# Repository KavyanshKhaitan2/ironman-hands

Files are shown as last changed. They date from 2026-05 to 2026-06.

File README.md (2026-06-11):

# Ironman-Hands!
[View in OnShape](https://cad.onshape.com/documents/6b24d13ccce8b20dadd52a3a/w/196c8f17dbb1cb6e287c322c/e/852bd395ec118001130bafdd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)

A glove which you can wear and control your computer by moving your hand and using gestures!! (It has a lot of sensors to do this!)

I will be stitching all the parts together on a glove, and then adding some more cloth on top so no exposed wires or PCBs are visible!

## Contents
Quickly jump to different parts of the README using this section!
1. [Why?](#why)
1. [Fallout Zine](#fallout-zine)
2. [PCB](#pcb)
3. [Schematics](#schematics)
4. [Case](#case)
5. [Bill of Materials](#bom)
6. [Assembly](#assembly)
## Why?
I watched the Iron Man Movie, and it was always fascinating to me how he controlled the screen using just his hands, so I decided to build to make that true and real!

## Fallout Zine
[Jump to Contents](#contents)

<image height="400" src="https://github.com/KavyanshKhaitan2/ironman-hands/blob/main/zine/Zine_PNG.png?raw=true">

- [ [Download JPEG file](https://github.com/KavyanshKhaitan2/ironman-hands/blob/main/zine/Zine_JPEG.jpg) ]
- [ [Download PNG file](https://github.com/KavyanshKhaitan2/ironman-hands/blob/main/zine/Zine_PNG.png) ]
- [ [Download High-Res PNG file](https://github.com/KavyanshKhaitan2/ironman-hands/blob/main/zine/Zine_PNG_HighRes.png) ]
- [ [Download Digital RGB PDF file](https://github.com/KavyanshKhaitan2/ironman-hands/blob/main/zine/Zine_Digital_RGB.pdf) ]
- [ [Download Print CMYK PDF file](https://github.com/KavyanshKhaitan2/ironman-hands/blob/main/zine/Zine_Print_CMYK.pdf) ]

[Jump to Contents](#contents)

## PCB
[Jump to Contents](#contents)

- [Mainboard](#mainboard)
- [Finger module](#finger-module)
- [BackLEDs](#backleds)
- [Power module](#power-module)

### Mainboard


- [ [Open in KiCanvas](https://kicanvas.org/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) ]

[Jump to Contents](#contents)

### Finger module


- [ [Open in KiCanvas](https://kicanvas.org/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) ]

[Jump to Contents](#contents)

### BackLEDs


- [ [Open in KiCanvas](https://kicanvas.org/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) ]

[Jump to Contents](#contents)

### Power module


- [ [Open in KiCanvas](https://kicanvas.org/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) ]

[Jump to Contents](#contents)

## Schematics
[Jump to Contents](#contents)

- [Mainboard](#mainboard-1)
- [Finger module P1](#finger-module-p1)
- [Finger module P2](#finger-module-p2)
- [Power module](#power-module-1)

### Mainboard


[ [View in KiCanvas](https://kicanvas.org/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) ]

[Jump to Contents](#contents)

### Finger module P1


[ [View in KiCanvas](https://kicanvas.org/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) ]

[Jump to Contents](#contents)

### Finger module P2


[ [View in KiCanvas](https://kicanvas.org/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) ]

[Jump to Contents](#contents)

### Power module


[ [View in KiCanvas](https://kicanvas.org/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) ]

[Jump to Contents](#contents)

## Case
### Final assembly:


[ [View in OnShape](https://cad.onshape.com/documents/6b24d13ccce8b20dadd52a3a/w/196c8f17dbb1cb6e287c322c/e/852bd395ec118001130bafdd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) ]

[Jump to Contents](#contents)

## BOM
(Bill of Materials)

[ [View in Google Sheets](https://docs.google.com/spreadsheets/d/10JJsmnbrsMaL60rsXx-CBmIgtjZ1htyX9JACOBp3yb4/edit?usp=sharing) ]
[ [Open CSV in GitHub](https://github.com/KavyanshKhaitan2/ironman-hands/blob/main/production/BOM.csv) ]

- [Cumulative](#cumulative)
- [Mainboard](#mainboard)
- [Per-finger module](#per-finger-module)
- [Power](#power)
- [Misc](#misc)

[Jump to Contents](#contents)

### Cumulative


[Jump to Contents](#contents)

### Mainboard
<table cellspacing="0" cellpadding="0">
    <tr>
        <th>
            <div>2</div>
        </th>
        <td>PCB</td>
        <td>0.4000</td>
        <td>
            <span>USD</span>
        </td>
        <td>-</td>
        <td>5</td>
        <td>1</td>
        <td>2.00</td>
        <td>USD</td>
        <td>₹191.36</td>
        <td>$2.00</td>
    </tr>
    <tr>
        <th>
            <div>3</div>
        </th>
        <td>Header pins (90deg)</td>
        <td>0.2000</td>
        <td>
            <span>INR</span>
        </td>
        <td>
            <a href="https://quartzcomponents.com/collections/all/products/male-90-degree-pin-header-connector"
                >QuartzComponents</a
            >
        </td>
        <td>40</td>
        <td>34</td>
        <td>8.00</td>
        <td>INR</td>
        <td>₹199.36</td>
        <td>$2.08</td>
    </tr>
    <tr>
        <th>
            <div>4</div>
        </th>
        <td>TYPE-C-31-M-12</td>
        <td>0.1719</td>
        <td>
            <span>USD</span>
        </td>
        <td>
            <a href="https://www.lcsc.com/product-detail/C165948.html">LCSC</a>
        </td>
        <td>5</td>
        <td>1</td>
        <td>0.86</td>
        <td>USD</td>
        <td>₹281.60</td>
        <td>$2.94</td>
    </tr>
    <tr>
        <th>
            <div>5</div>
        </th>
        <td>LM1117MP-3.3/TR</td>
        <td>0.0931</td>
        <td>
            <span>USD</span>
        </td>
        <td>
            <a href="https://www.lcsc.com/product-detail/C498153.html">LCSC</a>
        </td>
        <td>5</td>
        <td>1</td>
        <td>0.47</td>
        <td>USD</td>
        <td>₹326.14</td>
        <td>$3.41</td>
    </tr>
    <tr>
        <th>
            <div>6</div>
        </th>
        <td>SS56 Diode</td>
        <td>0.0471</td>
        <td>
            <span>USD</span>
        </td>
        <td>
            <a href="https://www.lcsc.com/product-detail/C65009.html">LCSC</a>
        </td>
        <td>10</td>
        <td>1</td>
        <td>0.47</td>
        <td>USD</td>
        <td>₹371.21</td>
        <td>$3.88</td>
    </tr>
    <tr>
        <th>
            <div>7</div>
        </th>
        <td>ESP32-S3-WROOM-1</td>
        <td>371.0000</td>
        <td>
            <span>INR</span>
        </td>
        <td>
            <a href="https://www.etstore.in/products/a2724">ETStore</a>
        </td>
        <td>1</td>
        <td>1</td>
        <td>371.00</td>
        <td>INR</td>
        <td>₹742.21</td>
        <td>$7.76</td>
    </tr>
    <tr>
        <th>
            <div>8</div>
        </th>
        <td>LSM6DS3TR-C</td>
        <td>1.5474</td>
        <td>
            <span>USD</span>
        </td>
        <td>
            <a href="https://www.lcsc.com/product-detail/C967633.html">LCSC</a>
        </td>
        <td>1</td>
        <td>1</td>
        <td>1.55</td>
        <td>USD</td>
        <td>₹890.27</td>
        <td>$9.30</td>
    </tr>
    <tr>
        <th>
            <div>9</div>
        </th>
        <td>TCA9548APWR</td>
        <td>0.6418</td>
        <td>
            <span>USD</span>
        </td>
        <td>
            <a href="https://www.lcsc.com/product-detail/C130026.html">LCSC</a>
        </td>
        <td>1</td>
        <td>1</td>
        <td>0.64</td>
        <td>USD</td>
        <td>₹951.68</td>
        <td>$9.95</td>
    </tr>
    <tr>
        <th>
            <div>10</div>
        </th>
        <td>SK6812MINI-E</td>
        <td>0.0870</td>
        <td>
            <span>USD</span>
        </td>
        <td>
            <a href="https://www.lcsc.com/product-detail/C5149201.html">LCSC</a>
        </td>
        <td>5</td>
        <td>6</td>
        <td>0.87</td>
        <td>USD</td>
        <td>₹1,034.92</td>
        <td>$10.82</td>
    </tr>
    <tr>
        <th>
            <div>11</div>
        </th>
        <td>10k 1206 resistor</td>
        <td>0.4500</td>
        <td>
            <span>INR</span>
        </td>
        <td>
            <a
                href="https://quartzcomponents.com/collections/all/products/yageo-510k-ohm-1206-package-1-4w-smd-resistor-1-tolerance-pack-of-20-pieces"
                >QuartzComponents</a
            >
        </td>
        <td>20</td>
        <td>2</td>
        <td>9.00</td>
        <td>INR</td>
        <td>₹1,043.92</td>
        <td>$10.91</td>
    </tr>
    <tr>
        <th>
            <div>12</div>
        </th>
        <td>100nF 0805 capacitor</td>
        <td>1.5000</td>
        <td>
            <span>INR</span>
        </td>
        <td>
            <a
                href="https://quartzcomponents.com/collections/all/products/100nf-0-1uf-104-50v-1206-smd-capacitor-pack-of-10-pieces"
                >QuartzComponents</a
            >
        </td>
        <td>10</td>
        <td>2</td>
        <td>15.00</td>
        <td>INR</td>
        <td>₹1,058.92</td>
        <td>$11.07</td>
    </tr>
</table>

[Jump to Contents](#contents)

### Per-finger module
<table cellspacing="0" cellpadding="0">
    <tbody>
        <tr>
            <td>Item Name</td>
            <td>
                <div>Unit Price</div>
            </td>
            <td>
                <div>Cur.</div>
            </td>
            <td>Link</td>
            <td>
                <div>Min Qty.</div>
            </td>
            <td>
                <div>Qty.</div>
            </td>
            <td>
                <div>Amount</div>
            </td>
            <td>Co1</td>
            <td>
                <div>1.. Run. Total</div>
            </td>
            <td>
                <div>2.. Run. Total</div>
            </td>
        </tr>
        <tr>
            <td>PCB</td>
            <td>0.4000</td>
            <td>
                <span>USD</span>
            </td>
            <td>-</td>
            <td>5</td>
            <td>4</td>
            <td>2.00</td>
            <td>USD</td>
            <td>₹191.36</td>
            <td>$2.00</td>
        </tr>
        <tr>
            <td>Header pins (90deg)</td>
            <td>0.2000</td>
            <td>
                <span>INR</span>
            </td>
            <td>
                <a href="https://quartzcomponents.com/collections/all/products/male-90-degree-pin-header-connector"
                    >QuartzComponents</a
                >
            </td>
            <td>40</td>
            <td>18</td>
            <td>8.00</td>
            <td>INR</td>
            <td>₹199.36</td>
            <td>$2.08</td>
        </tr>
        <tr>
            <td>LSM6DS3TR-C</td>
            <td>1.5474</td>
            <td>
                <span>USD</span>
            </td>
            <td>
                <a href="https://www.lcsc.com/product-detail/C967633.html">LCSC</a>
            </td>
            <td>1</td>
            <td>2</td>
            <td>3.09</td>
            <td>USD</td>
            <td>₹495.48</td>
            <td>$5.18</td>
        </tr>
        <tr>
            <td>10k 1206 resistor</td>
            <td>0.4500</td>
            <td>
                <span>INR</span>
            </td>
            <td>
                <a
                    href="https://quartzcomponents.com/collections/all/products/yageo-510k-ohm-1206-package-1-4w-smd-resistor-1-tolerance-pack-of-20-pieces"
                    >QuartzComponents</a
                >
            </td>
            <td>40</td>
            <td>4</td>
            <td>18.00</td>
            <td>INR</td>
            <td>₹513.48</td>
            <td>$5.37</td>
        </tr>
        <tr>
            <td>100nF 0805 capacitor</td>
            <td>1.5000</td>
            <td>
                <span>INR</span>
            </td>
            <td>
                <a
                    href="https://quartzcomponents.com/collections/all/products/100nf-0-1uf-104-50v-1206-smd-capacitor-pack-of-10-pieces"
                    >QuartzComponents</a
                >
            </td>
            <td>30</td>
            <td>4</td>
            <td>45.00</td>
            <td>INR</td>
            <td>₹558.48</td>
            <td>$5.84</td>
        </tr>
        <tr>
            <td>SK6812MINI-E</td>
            <td>0.0870</td>
            <td>
                <span>USD</span>
            </td>
            <td>
                <a href="https://www.lcsc.com/product-detail/C5149201.html">LCSC</a>
            </td>
            <td>5</td>
            <td>2</td>
            <td>0.44</td>
            <td>USD</td>
            <td>₹600.10</td>
            <td>$6.27</td>
        </tr>
    </tbody>
</table>

[Jump to Contents](#contents)

### Power

<table cellspacing="0" cellpadding="0">
    <tr>
        <td>Item Name</td>
        <td>Unit Price</td>
        <td>Cur.</td>
        <td>Link</td>
        <td>Min Qty.</td>
        <td>Qty.</td>
        <td>Amount</td>
        <td>Co1</td>
        <td>1.. Run. Total</td>
        <td>2.. Run. Total</td>
    </tr>
    <tr>
        <td>PCB</td>
        <td>1.4000</td>
        <td>USD</td>
        <td>-</td>
        <td>5</td>
        <td>1</td>
        <td>7.00</td>
        <td>USD</td>
        <td>₹669.78</td>
        <td>$7.00</td>
    </tr>
    <tr>
        <td>Header pins (90deg)</td>
        <td>0.2000</td>
        <td>INR</td>
        <td>
            <a href="https://quartzcomponents.com/collections/all/products/male-90-degree-pin-header-connector"
                >QuartzComponents</a
            >
        </td>
        <td>40</td>
        <td>16</td>
        <td>8.00</td>
        <td>INR</td>
        <td>₹8.00</td>
        <td>$0.08</td>
    </tr>
    <tr>
        <td>DC Barrel Jack</td>
        <td>6.0000</td>
        <td>INR</td>
        <td>
            <a href="https://quartzcomponents.com/products/female-dc-power-supply-connector-barrel-dc-jack"
                >QuartzComponents</a
            >
        </td>
        <td>1</td>
        <td>1</td>
        <td>6.00</td>
        <td>INR</td>
        <td>₹14.00</td>
        <td>$0.15</td>
    </tr>
    <tr>
        <td>DC Power Adapter</td>
        <td>132.0000</td>
        <td>
            <span>INR</span>
        </td>
        <td>
            <a href="https://quartzcomponents.com/products/12v-1a-dc-power-adapter">QuartzComponents</a>
        </td>
        <td>1</td>
        <td>1</td>
        <td>132.00</td>
        <td>INR</td>
        <td>₹146.00</td>
        <td>$1.53</td>
    </tr>
    <tr>
        <td>SPST Power Switch</td>
        <td>6.0000</td>
        <td>
            <span>INR</span>
        </td>
        <td>
            <a href="https://www.etstore.in/products/b8017">ETStore</a>
        </td>
        <td>2</td>
        <td>1</td>
        <td>12.00</td>
        <td>INR</td>
        <td>₹158.00</td>
        <td>$1.65</td>
    </tr>
    <tr>
        <td>TP5100 module</td>
        <td>57.0000</td>
        <td>
            <span>INR</span>
        </td>
        <td>
            <a
                href="https://quartzcomponents.com/collections/all/products/tp5100-4-2v-8-4v-li-ion-battery-charging-module"
                >QuartzComponents</a
            >
        </td>
        <td>1</td>
        <td>1</td>
        <td>57.00</td>
        <td>INR</td>
        <td>₹215.00</td>
        <td>$2.25</td>
    </tr>
    <tr>
        <td>TPS54302DDCR</td>
        <td>0.3140</td>
        <td>
            <span>USD</span>
        </td>
        <td>
            <a href="https://www.lcsc.com/product-detail/C311983.html">LCSC</a>
        </td>
        <td>5</td>
        <td>2</td>
        <td>1.57</td>
        <td>USD</td>
        <td>₹365.22</td>
        <td>$3.82</td>
    </tr>
    <tr>
        <td>22uF|3.55mOhm Cap</td>
        <td>0.0904</td>
        <td>
            <span>USD</span>
        </td>
        <td>
            <a href="https://www.lcsc.com/product-detail/C5677683.html">LCSC</a>
        </td>
        <td>5</td>
        <td>1</td>
        <td>0.45</td>
        <td>USD</td>
        <td>₹408.47</td>
        <td>$4.27</td>
    </tr>
    <tr>
        <td>100nF|280mOhm Cap</td>
        <td>0.0067</td>
        <td>
            <span>USD</span>
        </td>
        <td>
            <a href="https://www.lcsc.com/product-detail/C519980.html">LCSC</a>
        </td>
        <td>100</td>
        <td>2</td>
        <td>0.67</td>
        <td>USD</td>
        <td>₹472.58</td>
        <td>$4.94</td>
    </tr>
    <tr>
        <td>5uH|22mOhm Induc</td>
        <td>0.5559</td>
        <td>USD</td>
        <td>
            <a href="https://www.lcsc.com/product-detail/C780188.html">LCSC</a>
        </td>
        <td>2</td>
        <td>2</td>
        <td>1.11</td>
        <td>USD</td>
        <td>₹578.96</td>
        <td>$6.05</td>
    </tr>
    <tr>
        <td>47pF Cap</td>
        <td>1.3000</td>
        <td>INR</td>
        <td>
            <a
                href="https://quartzcomponents.com/collections/all/products/kemet-47pf-50v-805-smd-pack-c0g-multilayer-ceramic-capacitor-5-tolerence-pack-of-20"
                >QuartzComponents</a
            >
        </td>
        <td>20</td>
        <td>1</td>
        <td>26.00</td>
        <td>INR</td>
        <td>₹604.96</td>
        <td>$6.32</td>
    </tr>
    <tr>
        <td>100k 1206 resistor</td>
        <td>0.4500</td>
        <td>
            <span>INR</span>
        </td>
        <td>
            <a
                href="https://quartzcomponents.com/products/yageo-100k-ohm-1206-package-1-4w-smd-resistor-1-tolerance-pack-of-20-pieces"
                >QuartzComponents</a
            >
        </td>
        <td>20</td>
        <td>2</td>
        <td>9.00</td>
        <td>INR</td>
        <td>₹613.96</td>
        <td>$6.42</td>
    </tr>
    <tr>
        <td>13.7k 1206 resistor</td>
        <td>0.0059</td>
        <td>
            <span>USD</span>
        </td>
        <td>
            <a href="https://www.lcsc.com/product-detail/C2903322.html">LCSC</a>
        </td>
        <td>50</td>
        <td>1</td>
        <td>0.30</td>
        <td>USD</td>
        <td>₹642.18</td>
        <td>$6.71</td>
    </tr>
    <tr>
        <td>47uF 1210 capacitor</td>
        <td>0.1754</td>
        <td>
            <span>USD</span>
        </td>
        <td>
            <a href="https://www.lcsc.com/product-detail/C77101.html">LCSC</a>
        </td>
        <td>5</td>
        <td>3</td>
        <td>0.88</td>
        <td>USD</td>
        <td>₹726.10</td>
        <td>$7.59</td>
    </tr>
    <tr>
        <td>10uF 0805 capacitor</td>
        <td>0.0317</td>
        <td>
            <span>USD</span>
        </td>
        <td>
            <a href="https://www.lcsc.com/product-detail/C5677680.html">LCSC</a>
        </td>
        <td>20</td>
        <td>2</td>
        <td>0.63</td>
        <td>USD</td>
        <td>₹786.76</td>
        <td>$8.22</td>
    </tr>
    <tr>
        <td>3.3uH inductor</td>
        <td>0.5559</td>
        <td>
            <span>USD</span>
        </td>
        <td>
            <a href="https://www.lcsc.com/product-detail/C780188.html">LCSC</a>
        </td>
        <td>2</td>
        <td>2</td>
        <td>1.11</td>
        <td>USD</td>
        <td>₹893.14</td>
        <td>$9.33</td>
    </tr>
    <tr>
        <td>82pF 0805 capacitor</td>
        <td>0.0315</td>
        <td>
            <span>USD</span>
        </td>
        <td>
            <a href="https://www.lcsc.com/product-detail/C597385.html">LCSC</a>
        </td>
        <td>5</td>
        <td>1</td>
        <td>0.16</td>
        <td>USD</td>
        <td>₹908.21</td>
        <td>$9.49</td>
    </tr>
    <tr>
        <td>22k 1206 resistor</td>
        <td>0.4500</td>
        <td>
            <span>INR</span>
        </td>
        <td>
            <a
                href="https://quartzcomponents.com/products/yageo-22k-ohm-1206-package-1-4w-smd-resistor-1-tolerance-pack-of-20-pieces"
                >QuartzComponents</a
            >
        </td>
        <td>20</td>
        <td>1</td>
        <td>9.00</td>
        <td>INR</td>
        <td>₹917.21</td>
        <td>$9.59</td>
    </tr>
    <tr>
        <td>100 THT resistor</td>
        <td>0.8000</td>
        <td>
            <span>INR</span>
        </td>
        <td>
            <a href="https://quartzcomponents.com/products/100-ohm-1-4-watt-resistor-with-1-tolerance-pack-of-10"
                >QuartzComponents</a
            >
        </td>
        <td>10</td>
        <td>1</td>
        <td>8.00</td>
        <td>INR</td>
        <td>₹925.21</td>
        <td>$9.67</td>
    </tr>
    <tr>
        <td>47 THT resistor</td>
        <td>0.8000</td>
        <td>
            <span>INR</span>
        </td>
        <td>
            <a href="https://quartzcomponents.com/products/47-ohm-1-4-watt-resistor-with-1-tolerance-pack-of-10"
                >QuartzComponents</a
            >
        </td>
        <td>10</td>
        <td>1</td>
        <td>8.00</td>
        <td>INR</td>
        <td>₹933.21</td>
        <td>$9.75</td>
    </tr>
</table>

[Jump to Contents](#contents)

### Misc

<table cellspacing="0" cellpadding="0">
    <tbody>
        <tr>
            <td>Item Name</td>
            <td>Unit Price</td>
            <td>Cur.</td>
            <td>Link</td>
            <td>Min Qty.</td>
            <td>Qty.</td>
            <td>Amount</td>
            <td>Co1</td>
            <td>1.. Run. Total</td>
            <td>2.. Run. Total</td>
        </tr>
        <tr>
            <td>Gloves</td>
            <td>499.0000</td>
            <td>
                <span>INR</span>
            </td>
            <td>
                <a href="https://www.decathlon.in/p/8543424/men-golf-resistance-glove-right-handed-black-and-white"
                    >Decathlon</a
                >
            </td>
            <td>1</td>
            <td>1</td>
            <td>499.00</td>
            <td>INR</td>
            <td>₹499.00</td>
            <td>$5.22</td>
        </tr>
        <tr>
            <td>Female-to-Female Jumper Wires</td>
            <td>1.0500</td>
            <td>
                <span>INR</span>
            </td>
            <td>
                <a
                    href="https://quartzcomponents.com/collections/all/products/female-to-female-connecting-wires-jumper-wires-set-of-40"
                    >QuartzComponents</a
                >
            </td>
            <td>40</td>
            <td>55</td>
            <td>84.00</td>
            <td>INR</td>
            <td>₹583.00</td>
            <td>$6.09</td>
        </tr>
    </tbody>
</table>

[Jump to Contents](#contents)

# Assembly
1. Prep your PCB and solder all the components
2. Take the finger modules and then stitch it to the gloves (the numbered pins are meant to be used as mounting holes)


3. Take the mainboard case and stitch it to the gloves (these holes are provided so you can easily stitch it like buttons on a shirt)


4. Put the mainboard inside the case
5. Connect them using jumper wires
6. Stitch some extra fabric on top of the finger modules
7. Stitch velcro straps to the power module


8. Place power module PCB inside the case
9. Connect em again
10. Charge your batteries

## Wiring diagram



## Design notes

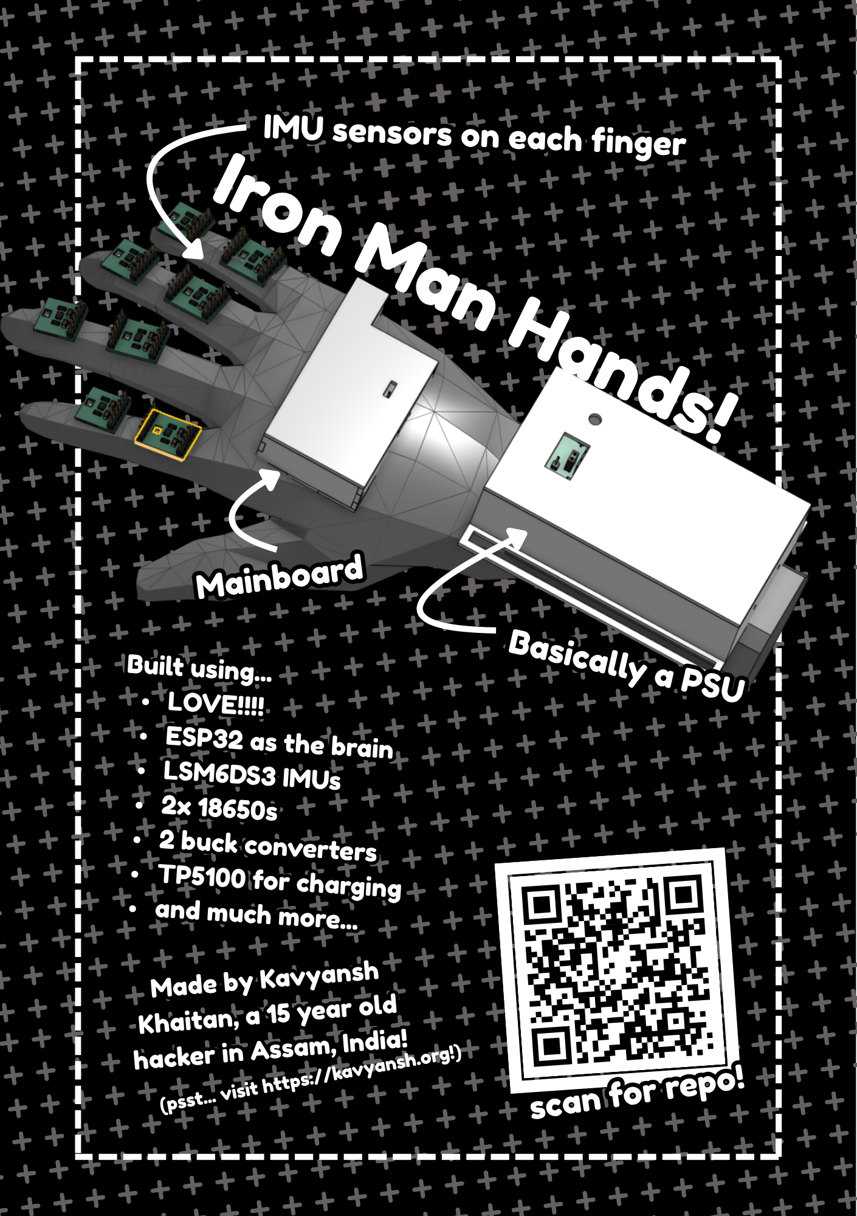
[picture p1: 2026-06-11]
zine/Zine_PNG.png

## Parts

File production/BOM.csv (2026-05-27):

Item Name | Unit Price | Cur. | Link | Column 11 | Min Qty. | Qty. | Amount | Co1 | 1.. Run. Total | 2.. Run. Total
Mainboard PCB | 0.4000 | USD | jlcpcb.com | http://jlcpcb.com/ | 5 | 1 | 2.00 | USD | ₹191.51 | $2.00
Per-finger module PCB | 0.4000 | USD | jlcpcb.com | http://jlcpcb.com/ | 5 | 4 | 2.00 | USD | ₹191.51 | $2.00
Power module PCB | 1.4000 | USD | jlcpcb.com | http://jlcpcb.com/ | 5 | 1 | 7.00 | USD | ₹861.80 | $9.00
Header pins (90deg) | 0.2000 | INR | QuartzComponents | https://quartzcomponents.com/collections/all/products/male-90-degree-pin-header-connector | 40 | 122 | 32.00 | INR | ₹223.51 | $2.33
TYPE-C-31-M-12 | 0.1719 | USD | LCSC | https://www.lcsc.com/product-detail/C165948.html | 5 | 1 | 0.86 | USD | ₹305.81 | $3.19
LM1117MP-3.3/TR | 0.0931 | USD | LCSC | https://www.lcsc.com/product-detail/C498153.html | 5 | 1 | 0.47 | USD | ₹350.39 | $3.66
SS56 Diode | 0.0471 | USD | LCSC | https://www.lcsc.com/product-detail/C65009.html | 10 | 1 | 0.47 | USD | ₹395.49 | $4.13
ESP32-S3-WROOM-1 | 371.0000 | INR | ETStore | https://www.etstore.in/products/a2724 | 1 | 1 | 371.00 | INR | ₹766.49 | $8.00
LSM6DS3TR-C | 1.5474 | USD | LCSC | https://www.lcsc.com/product-detail/C967633.html | 1 | 9 | 13.93 | USD | ₹2,100.04 | $21.93
TCA9548APWR | 0.6418 | USD | LCSC | https://www.lcsc.com/product-detail/C130026.html | 1 | 1 | 0.64 | USD | ₹2,161.50 | $22.57
SK6812MINI-E | 0.0870 | USD | LCSC | https://www.lcsc.com/product-detail/C5149201.html | 5 | 14 | 1.31 | USD | ₹2,286.46 | $23.88
10k 1206 resistor | 0.4500 | INR | QuartzComponents | https://quartzcomponents.com/collections/all/products/yageo-510k-ohm-1206-package-1-4w-smd-resistor-1-tolerance-pack-of-20-pieces | 20 | 2 | 9.00 | INR | ₹2,295.46 | $23.97
100nF 0805 capacitor | 1.5000 | INR | QuartzComponents | https://quartzcomponents.com/collections/all/products/100nf-0-1uf-104-50v-1206-smd-capacitor-pack-of-10-pieces | 10 | 2 | 15.00 | INR | ₹2,310.46 | $24.13
10k 1206 resistor | 0.4500 | INR | QuartzComponents | https://quartzcomponents.com/collections/all/products/yageo-510k-ohm-1206-package-1-4w-smd-resistor-1-tolerance-pack-of-20-pieces | 40 | 16 | 18.00 | INR | ₹2,328.46 | $24.32
100nF 0805 capacitor | 1.5000 | INR | QuartzComponents | https://quartzcomponents.com/collections/all/products/100nf-0-1uf-104-50v-1206-smd-capacitor-pack-of-10-pieces | 30 | 16 | 45.00 | INR | ₹2,373.46 | $24.79
DC Barrel Jack | 6.0000 | INR | QuartzComponents | https://quartzcomponents.com/products/female-dc-power-supply-connector-barrel-dc-jack | 1 | 1 | 6.00 | INR | ₹2,379.46 | $24.85
DC Power Adapter | 132.0000 | INR | QuartzComponents | https://quartzcomponents.com/products/12v-1a-dc-power-adapter | 1 | 1 | 132.00 | INR | ₹2,511.46 | $26.23
SPST Power Switch | 6.0000 | INR | ETStore | https://www.etstore.in/products/b8017 | 2 | 1 | 12.00 | INR | ₹2,523.46 | $26.35
TP5100 module | 57.0000 | INR | QuartzComponents | https://quartzcomponents.com/collections/all/products/tp5100-4-2v-8-4v-li-ion-battery-charging-module | 1 | 1 | 57.00 | INR | ₹2,580.46 | $26.95
TPS54302DDCR | 0.3140 | USD | LCSC | https://www.lcsc.com/product-detail/C311983.html | 5 | 2 | 1.57 | USD | ₹2,730.80 | $28.52
22uF|3.55mOhm Cap | 0.0904 | USD | LCSC | https://www.lcsc.com/product-detail/C5677683.html | 5 | 1 | 0.45 | USD | ₹2,774.08 | $28.97
100nF|280mOhm Cap | 0.0067 | USD | LCSC | https://www.lcsc.com/product-detail/C519980.html | 100 | 2 | 0.67 | USD | ₹2,838.23 | $29.64
5uH|22mOhm Induc | 0.5559 | USD | LCSC | https://www.lcsc.com/product-detail/C780188.html | 2 | 2 | 1.11 | USD | ₹2,944.70 | $30.75
47pF Cap | 1.3000 | INR | QuartzComponents | https://quartzcomponents.com/collections/all/products/kemet-47pf-50v-805-smd-pack-c0g-multilayer-ceramic-capacitor-5-tolerence-pack-of-20 | 20 | 1 | 26.00 | INR | ₹2,970.70 | $31.02
100k 1206 resistor | 0.4500 | INR | QuartzComponents | https://quartzcomponents.com/products/yageo-100k-ohm-1206-package-1-4w-smd-resistor-1-tolerance-pack-of-20-pieces | 20 | 2 | 9.00 | INR | ₹2,979.70 | $31.12
13.7k 1206 resistor | 0.0059 | USD | LCSC | https://www.lcsc.com/product-detail/C2903322.html | 50 | 1 | 0.30 | USD | ₹3,007.94 | $31.41
47uF 1210 capacitor | 0.1754 | USD | LCSC | https://www.lcsc.com/product-detail/C77101.html | 5 | 3 | 0.88 | USD | ₹3,091.92 | $32.29
10uF 0805 capacitor | 0.0317 | USD | LCSC | https://www.lcsc.com/product-detail/C5677680.html | 20 | 2 | 0.63 | USD | ₹3,152.63 | $32.92
3.3uH inductor | 0.5559 | USD | LCSC | https://www.lcsc.com/product-detail/C780188.html | 2 | 2 | 1.11 | USD | ₹3,259.09 | $34.04
82pF 0805 capacitor | 0.0315 | USD | LCSC | https://www.lcsc.com/product-detail/C597385.html | 5 | 1 | 0.16 | USD | ₹3,274.17 | $34.19
22k 1206 resistor | 0.4500 | INR | QuartzComponents | https://quartzcomponents.com/products/yageo-22k-ohm-1206-package-1-4w-smd-resistor-1-tolerance-pack-of-20-pieces | 20 | 1 | 9.00 | INR | ₹3,283.17 | $34.29
100 THT resistor | 0.8000 | INR | QuartzComponents | https://quartzcomponents.com/products/100-ohm-1-4-watt-resistor-with-1-tolerance-pack-of-10 | 10 | 1 | 8.00 | INR | ₹3,291.17 | $34.37
47 THT resistor | 0.8000 | INR | QuartzComponents | https://quartzcomponents.com/products/47-ohm-1-4-watt-resistor-with-1-tolerance-pack-of-10 | 10 | 1 | 8.00 | INR | ₹3,299.17 | $34.45
Gloves | 499.0000 | INR | Decathlon | https://www.decathlon.in/p/8543424/men-golf-resistance-glove-right-handed-black-and-white | 1 | 1 | 499.00 | INR | ₹3,798.17 | $39.67
Female-to-Female Jumper Wires | 1.0500 | INR | QuartzComponents | https://quartzcomponents.com/collections/all/products/female-to-female-connecting-wires-jumper-wires-set-of-40 | 40 | 55 | 84.00 | INR | ₹3,882.17 | $40.54

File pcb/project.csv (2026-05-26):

Reference | Qty | Value | DNP | Exclude from BOM | Exclude from Board | Footprint | Datasheet
C1,C7,C8,C9,C10,C11,C15 | 7 | 100nF |  |  |  | Capacitor_SMD:C_1206_3216Metric_Pad1.33x1.80mm_HandSolder
C5,C6 | 2 | 100nF |  |  | Excluded from board
D9,D10,D11,D12,D13,D14,D18,D19,D21,D23,D25,D27,D29,D31 | 14 | SK6812MINI-E |  |  |  | LED_SMD:LED_SK6812MINI-E_3.2x2.8mm_P1.5mm_ReverseMount | https://www.lcsc.com/datasheet/C5149201.pdf
D15 | 1 | D |  |  |  | Diode_SMD:D_SMA_Handsoldering
J1 | 1 | USB_C_Receptacle_USB2.0_14P |  |  |  | Connector_USB:USB_C_Receptacle_HRO_TYPE-C-31-M-12 | https://www.usb.org/sites/default/files/documents/usb_type-c.zip
J2,J3 | 2 | Conn_01x03 |  |  |  | Connector_PinHeader_2.54mm:PinHeader_1x03_P2.54mm_Vertical
J12 | 1 | Conn_01x04 |  |  |  | Connector_PinSocket_2.54mm:PinSocket_1x04_P2.54mm_Vertical
J18,J19,J20,J24,J25,J28,J29,J33,J36,J37,J39,J40,J42,J43,J44,J45 | 16 | Conn_01x06 |  |  |  | Connector_PinHeader_2.54mm:PinHeader_1x06_P2.54mm_Vertical
R2,R7,R8,R9,R10,R11,R12,R15 | 8 | 10k |  |  |  | Resistor_SMD:R_1206_3216Metric_Pad1.30x1.75mm_HandSolder
R5,R6 | 2 | 10k
U1 | 1 | LM1117MP-3.3 |  |  |  | Package_TO_SOT_SMD:SOT-223-3_TabPin2 | http://www.ti.com/lit/ds/symlink/lm1117.pdf
U2,U3,U6,U8,U10,U15,U18,U20,U22 | 9 | LSM6DS3 |  |  |  | Package_LGA:LGA-14_3x2.5mm_P0.5mm_LayoutBorder3x4y | https://www.st.com/resource/en/datasheet/lsm6ds3tr-c.pdf
U4 | 1 | ESP32-S3-WROOM-1 |  |  |  | RF_Module:ESP32-S3-WROOM-1 | https://www.espressif.com/sites/default/files/documentation/esp32-s3-wroom-1_wroom-1u_datasheet_en.pdf
U16 | 1 | TCA9548APWR |  |  |  | Package_SO:TSSOP-24_4.4x7.8mm_P0.65mm | http://www.ti.com/lit/ds/symlink/tca9548a.pdf

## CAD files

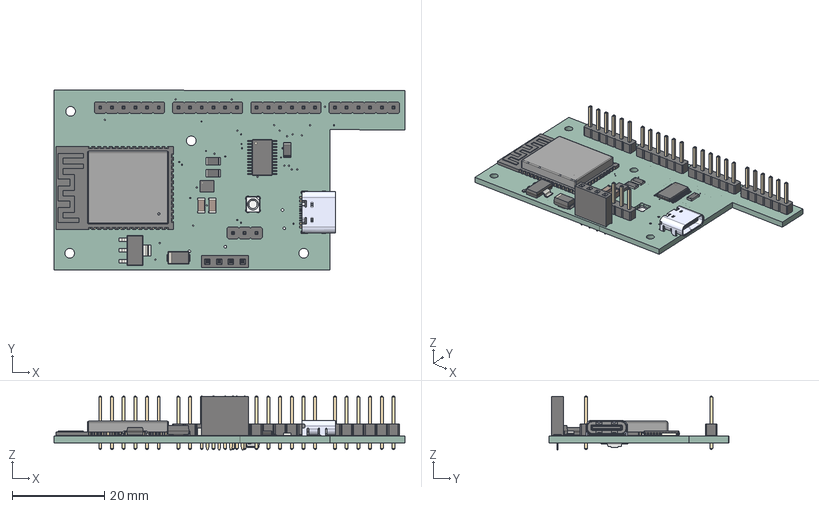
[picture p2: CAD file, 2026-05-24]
pcb/v1_mainboard.step
76.2 x 39.0 x 11.6 mm
C_1206_3216Metric x 2
R_1206_3216Metric x 3
PinHeader_1x06_P2.54mm_Vertical x 4
LGA-14_3x2.5mm_P0.5mm_LayoutBorder3x4y
TSSOP-24_4.4x7.8mm_P0.65mm
PinSocket_1x04_P2.54mm_Vertical
D_SMA
PinHeader_1x03_P2.54mm_Vertical
TYPE-C-31-M-12
SOT-223
ESP32-S3-WROOM-1
Pin1
Pin2
Pin3
Pin4
mainboard_PCB

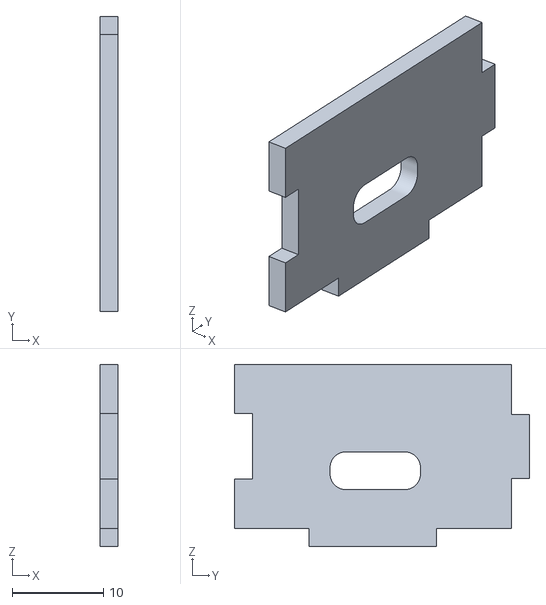
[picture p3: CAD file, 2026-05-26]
production/3dmodels/all_models/Mainboard case - Part 5.stl
2.01 x 32.4 x 20.0

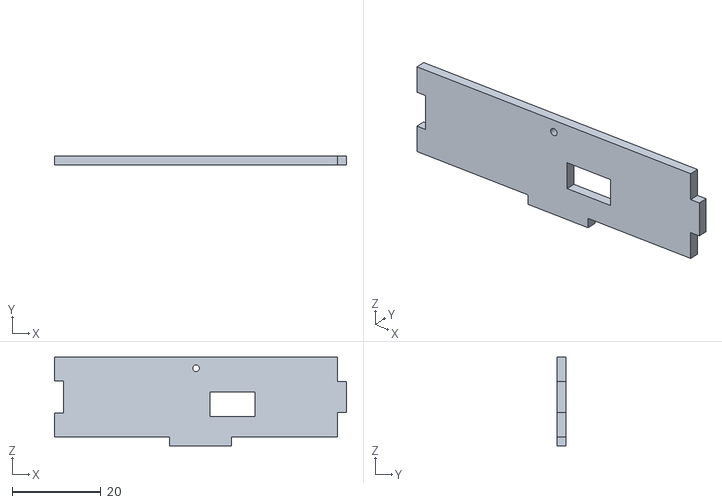
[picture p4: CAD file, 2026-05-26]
production/3dmodels/all_models/Mainboard case - Part 6.stl
65.9 x 2.00 x 20.0

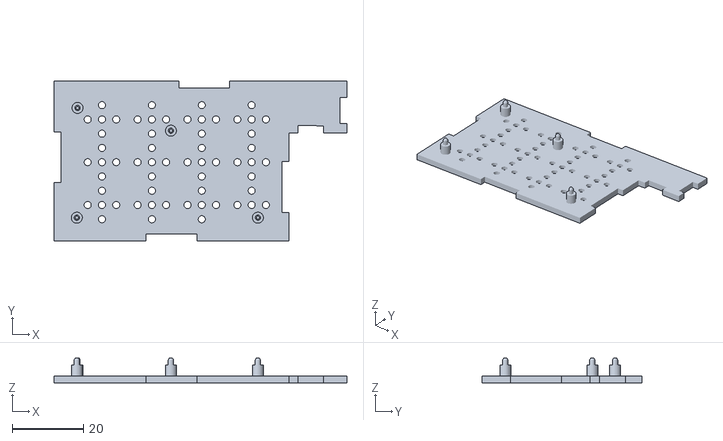
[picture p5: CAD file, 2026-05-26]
production/3dmodels/all_models/Mainboard case - Part 8.stl
82.2 x 45.0 x 7.00

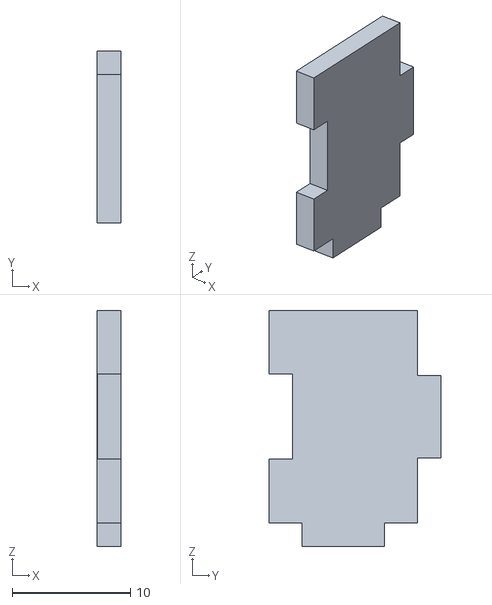
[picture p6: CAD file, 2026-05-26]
production/3dmodels/all_models/Mainboard case - Part 3.stl
2.00 x 14.6 x 20.0

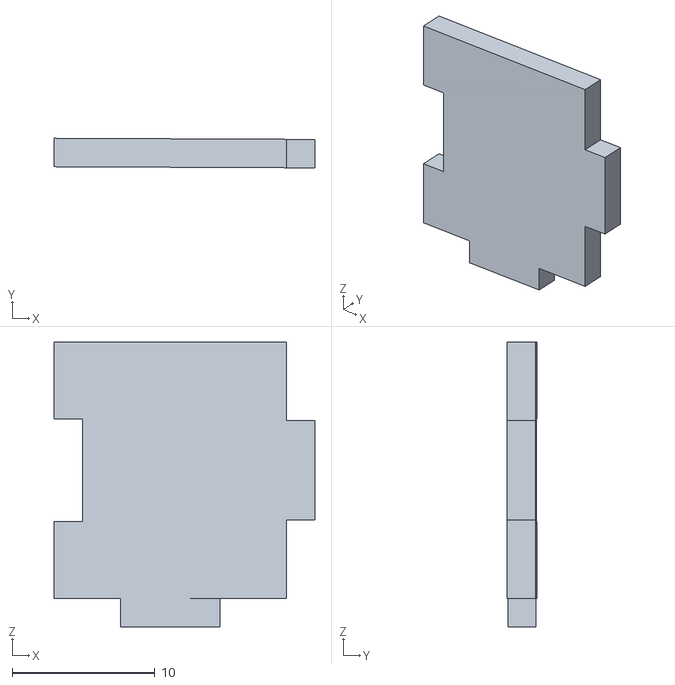
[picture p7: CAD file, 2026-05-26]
production/3dmodels/all_models/Mainboard case - Part 4.stl
18.3 x 2.07 x 20.0

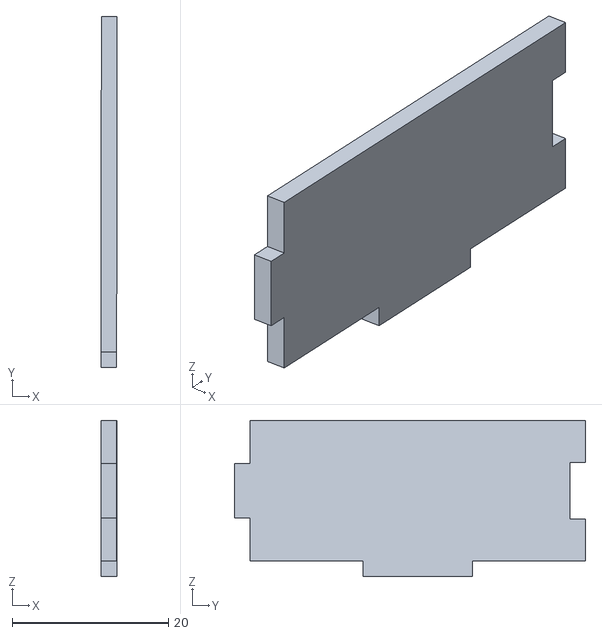
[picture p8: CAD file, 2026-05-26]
production/3dmodels/all_models/Mainboard case - Part 1.stl
2.02 x 45.0 x 20.0

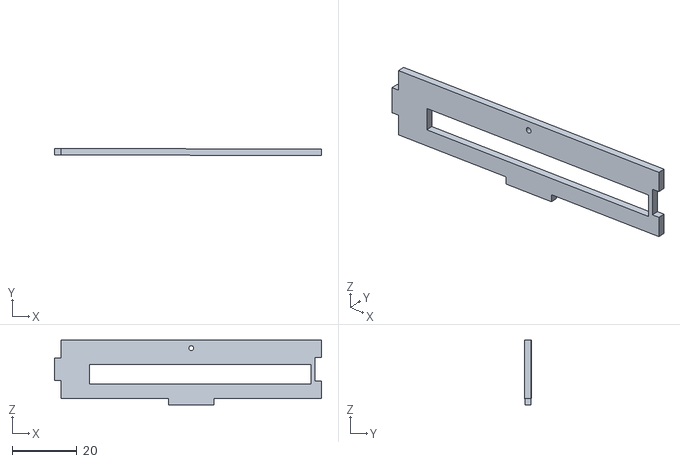
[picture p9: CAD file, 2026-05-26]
production/3dmodels/all_models/Mainboard case - Part 2.stl
82.2 x 2.04 x 20.0

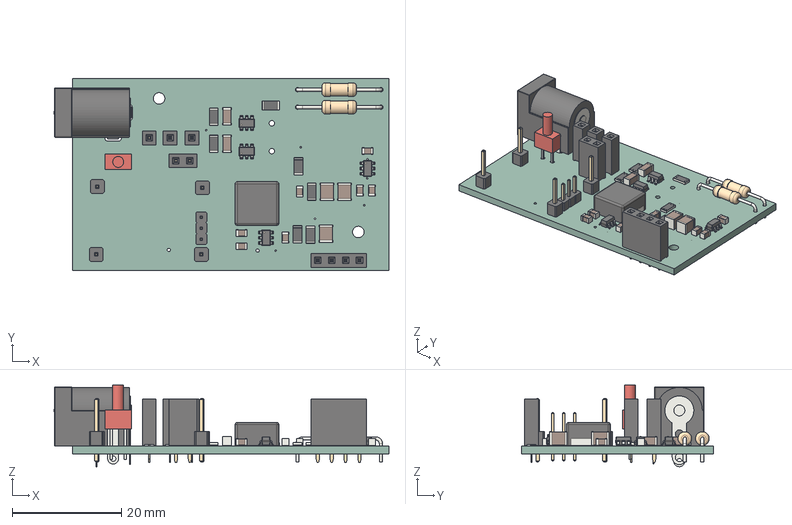
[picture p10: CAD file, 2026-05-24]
pcb/battery_module/battery_module/v1_3dmodel.step
61.2 x 35.0 x 14.9 mm
R_1206_3216Metric x 7
PinHeader_1x01_P2.54mm_Vertical x 4
C_1210_3225Metric x 3
PinSocket_1x02_P2.54mm_Vertical
R_Axial_DIN0207_L6.3mm_D2.5mm_P15.24mm_Horizontal x 2
PinHeader_1x03_P2.00mm_Vertical
C_0805_2012Metric x 7
C_1206_3216Metric x 2
SOT-23-6 x 4
PinSocket_1x01_P2.54mm_Vertical x 3
PinSocket_1x04_P2.54mm_Vertical
L_APV_ANR8040
BarrelJack_Horizontal
LED_D2.0mm_W4.0mm_H2.8mm_FlatTop
battery_module_PCB

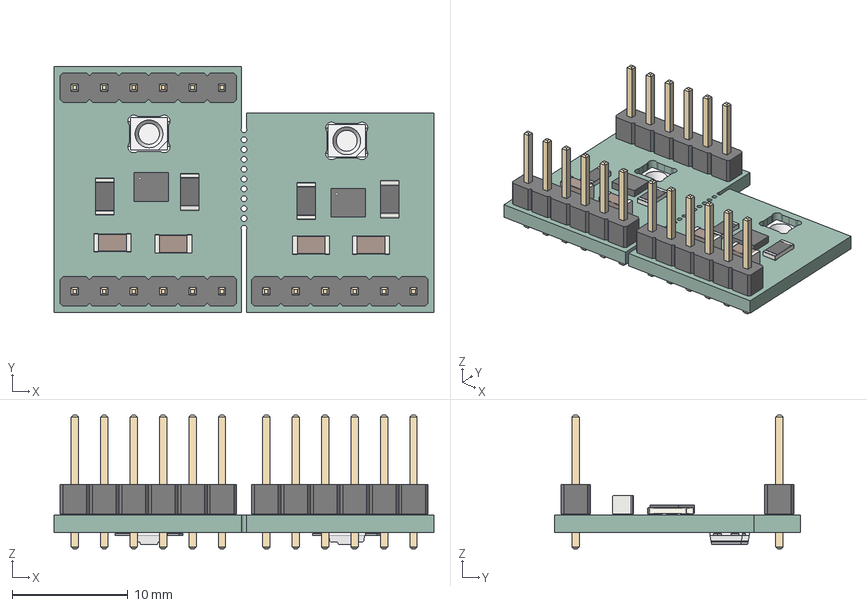
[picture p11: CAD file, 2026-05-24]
pcb/v1_fingermods.step
32.8 x 21.2 x 11.5 mm
C_1206_3216Metric x 4
R_1206_3216Metric x 4
LGA-14_3x2.5mm_P0.5mm_LayoutBorder3x4y x 2
PinHeader_1x06_P2.54mm_Vertical x 3
Pin1 x 2
Pin2 x 2
Pin3 x 2
Pin4 x 2
finger-mods_PCB

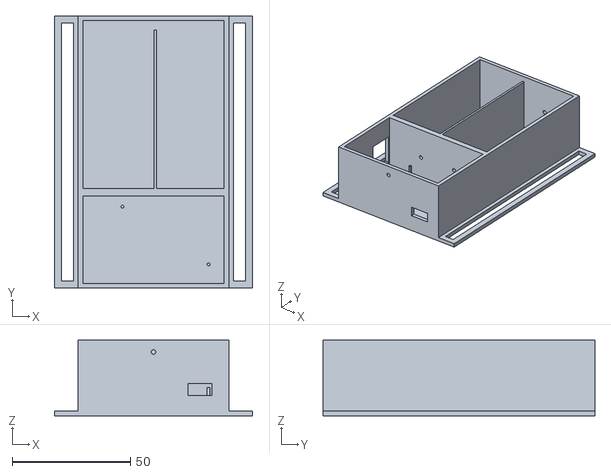
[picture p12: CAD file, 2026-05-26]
production/3dmodels/all_models/Power module case - Part 1.stl
83.8 x 115.1 x 32.0

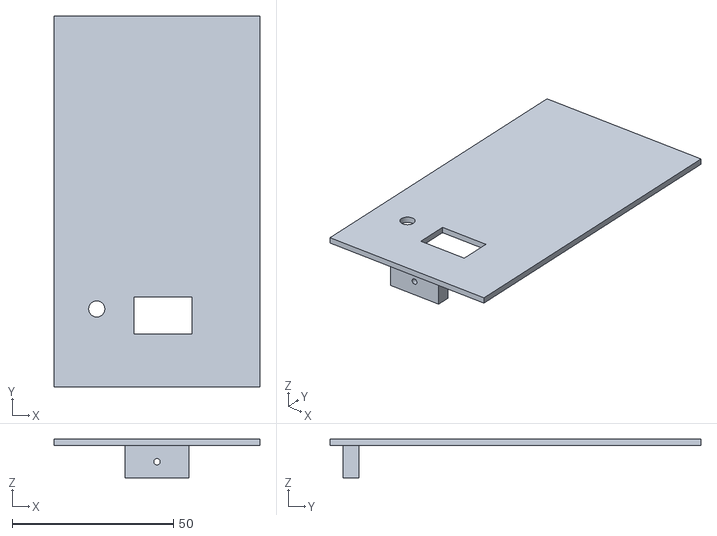
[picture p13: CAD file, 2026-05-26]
production/3dmodels/all_models/Power module case - Part 2.stl
63.8 x 115.1 x 12.0

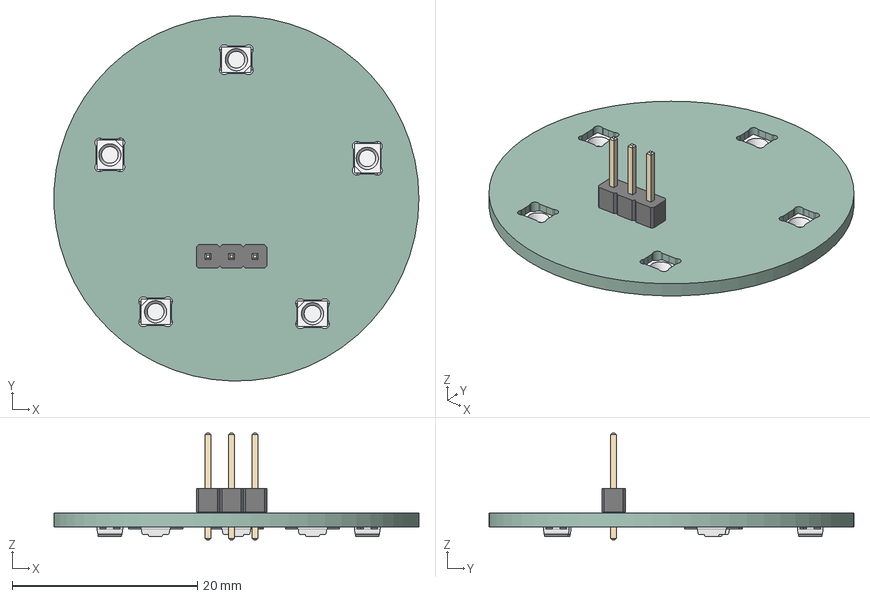
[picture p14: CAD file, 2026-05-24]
pcb/v1_backleds.step
39.4 x 39.4 x 11.5 mm
PinHeader_1x03_P2.54mm_Vertical
Pin1 x 5
Pin2 x 5
Pin3 x 5
Pin4 x 5
backleds_PCB

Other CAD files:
pcb/battery_module/battery_module/.step

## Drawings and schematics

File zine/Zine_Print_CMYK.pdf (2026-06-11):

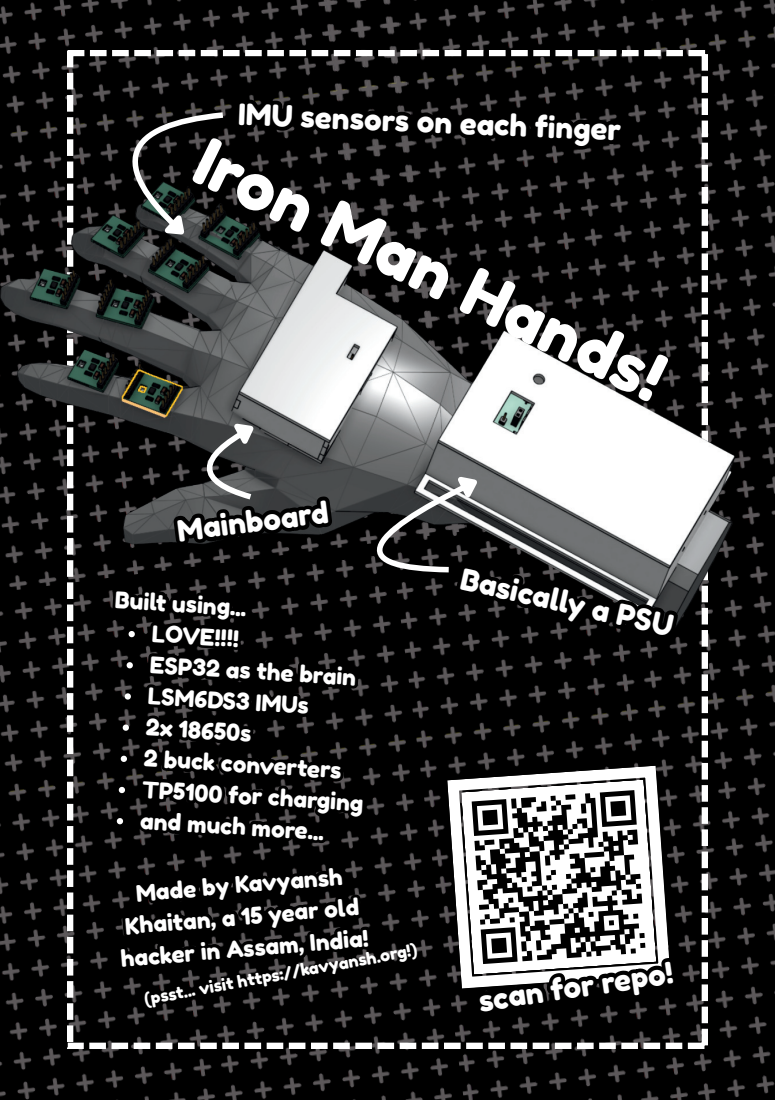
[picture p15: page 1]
Basically a PSU; Mainboard; Built using... LOVE!!!!; LSM6DS3 IMUs 2x 18650s 2 buck converters TP5100 for charging

IMU sensors on each finger

Iron Man Hands!

ESP32 as the brain

and much more...

Made by Kavyansh

Khaitan, a 15 year old

hacker in Assam, India!

(psst... visit https://kavyansh.org!)

scan for repo!

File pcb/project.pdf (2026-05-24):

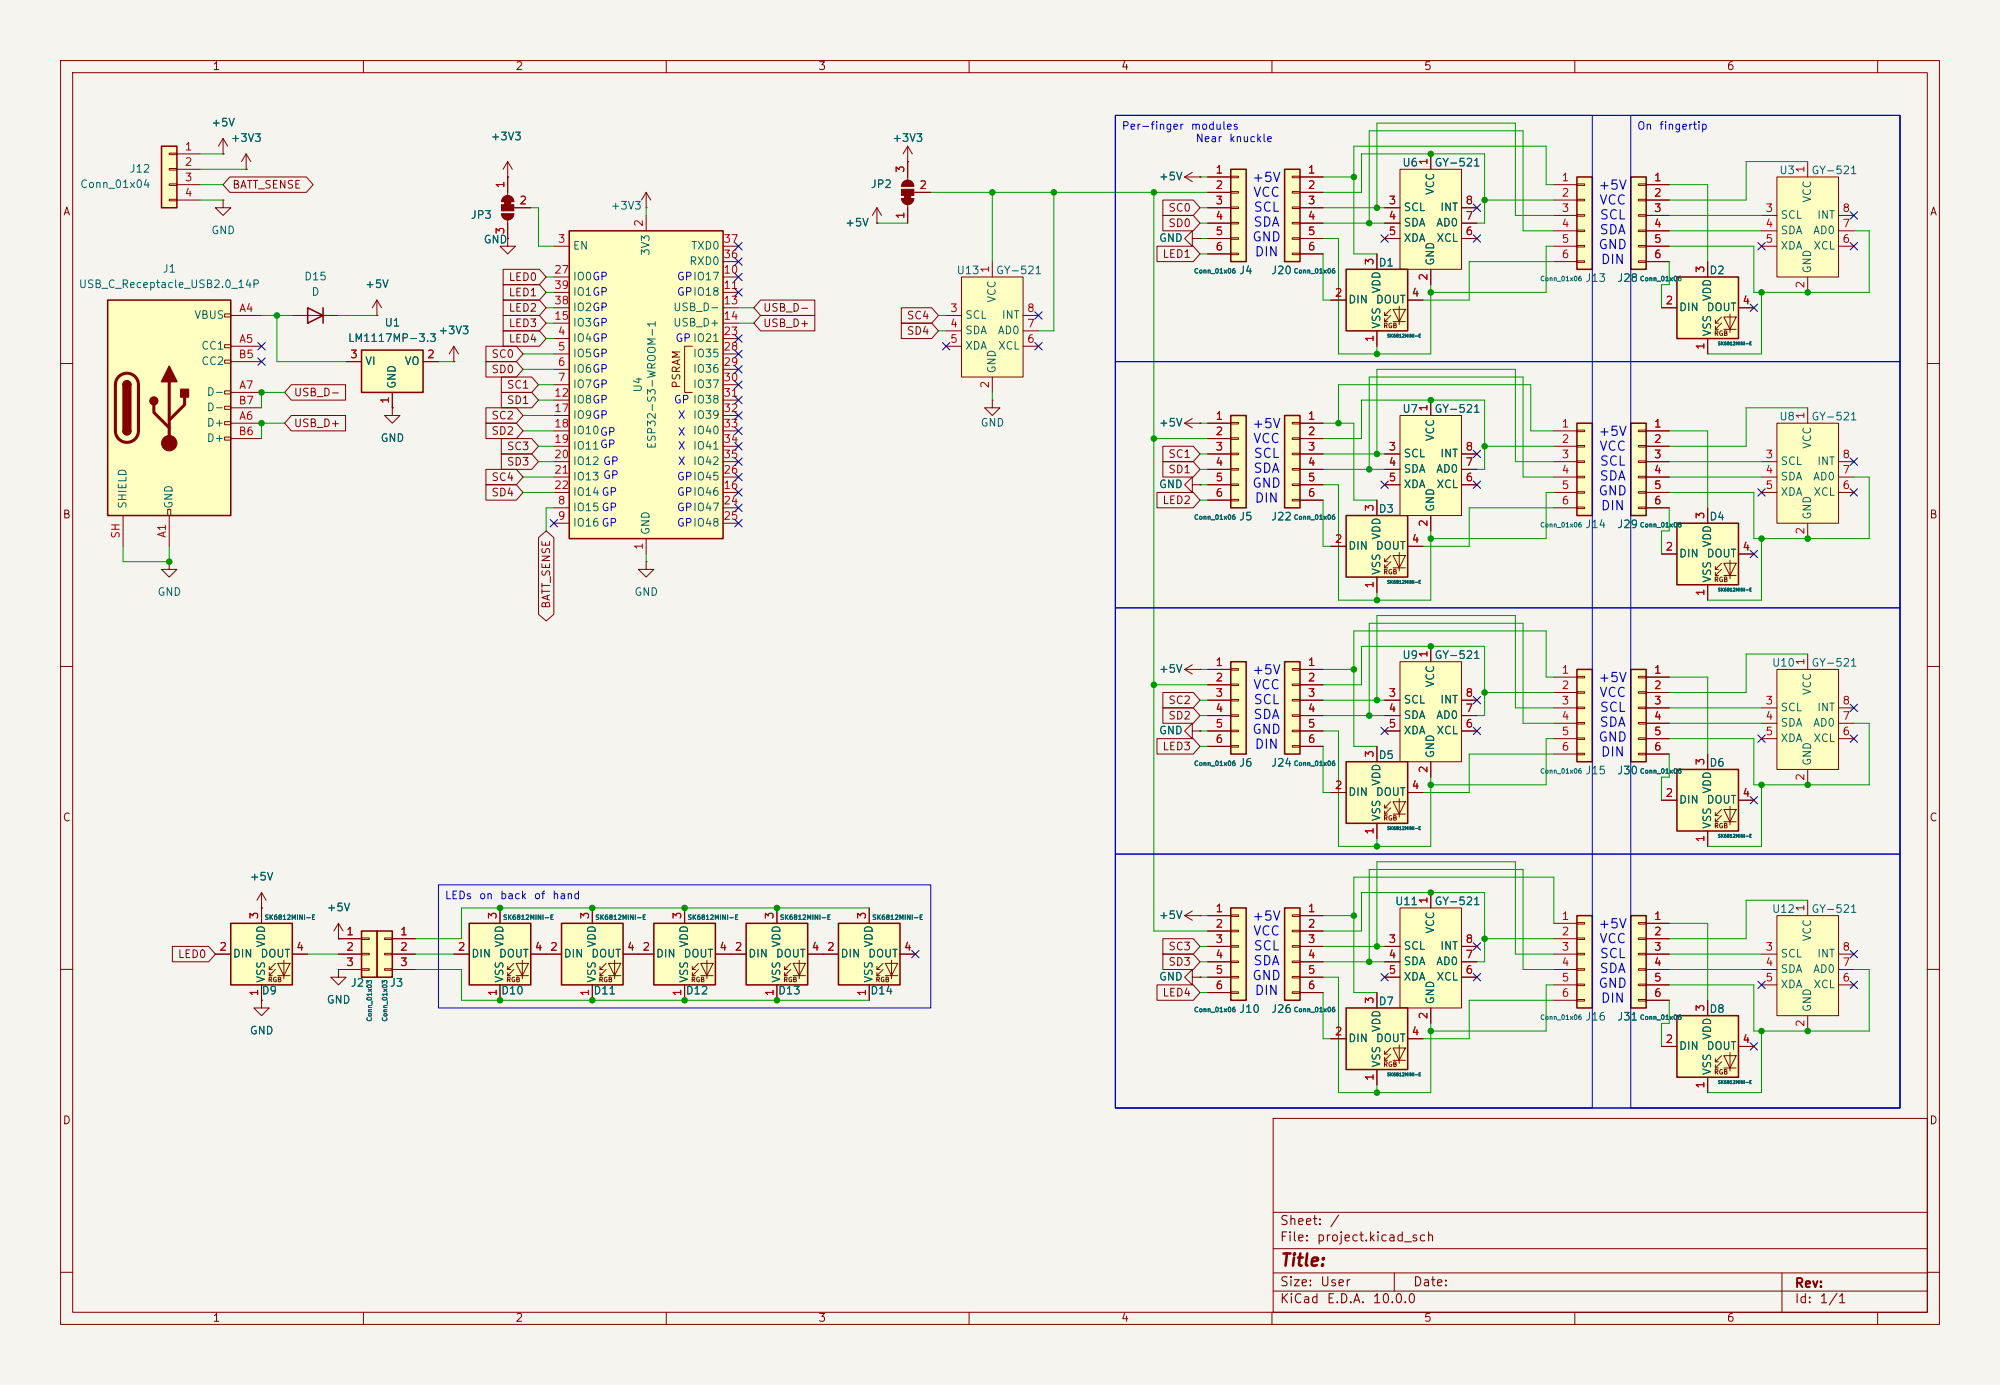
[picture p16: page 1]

VCC SCL SDA GND DIN

3 | | 3 3
4 | | 4 4 | | SDA 4

5 5 | XDA 5

J29 Conn_01x06 VCC SCL SDA GND | VSS RGB 1 DIN 2 VDD

VCC SCL SDA GND

4 4

VCC SCL SDA GND DIN | SK6812MINI-E 1

Size: User | Rev:
KiCad E.D.A. 10.0.0 | Id: 1/1

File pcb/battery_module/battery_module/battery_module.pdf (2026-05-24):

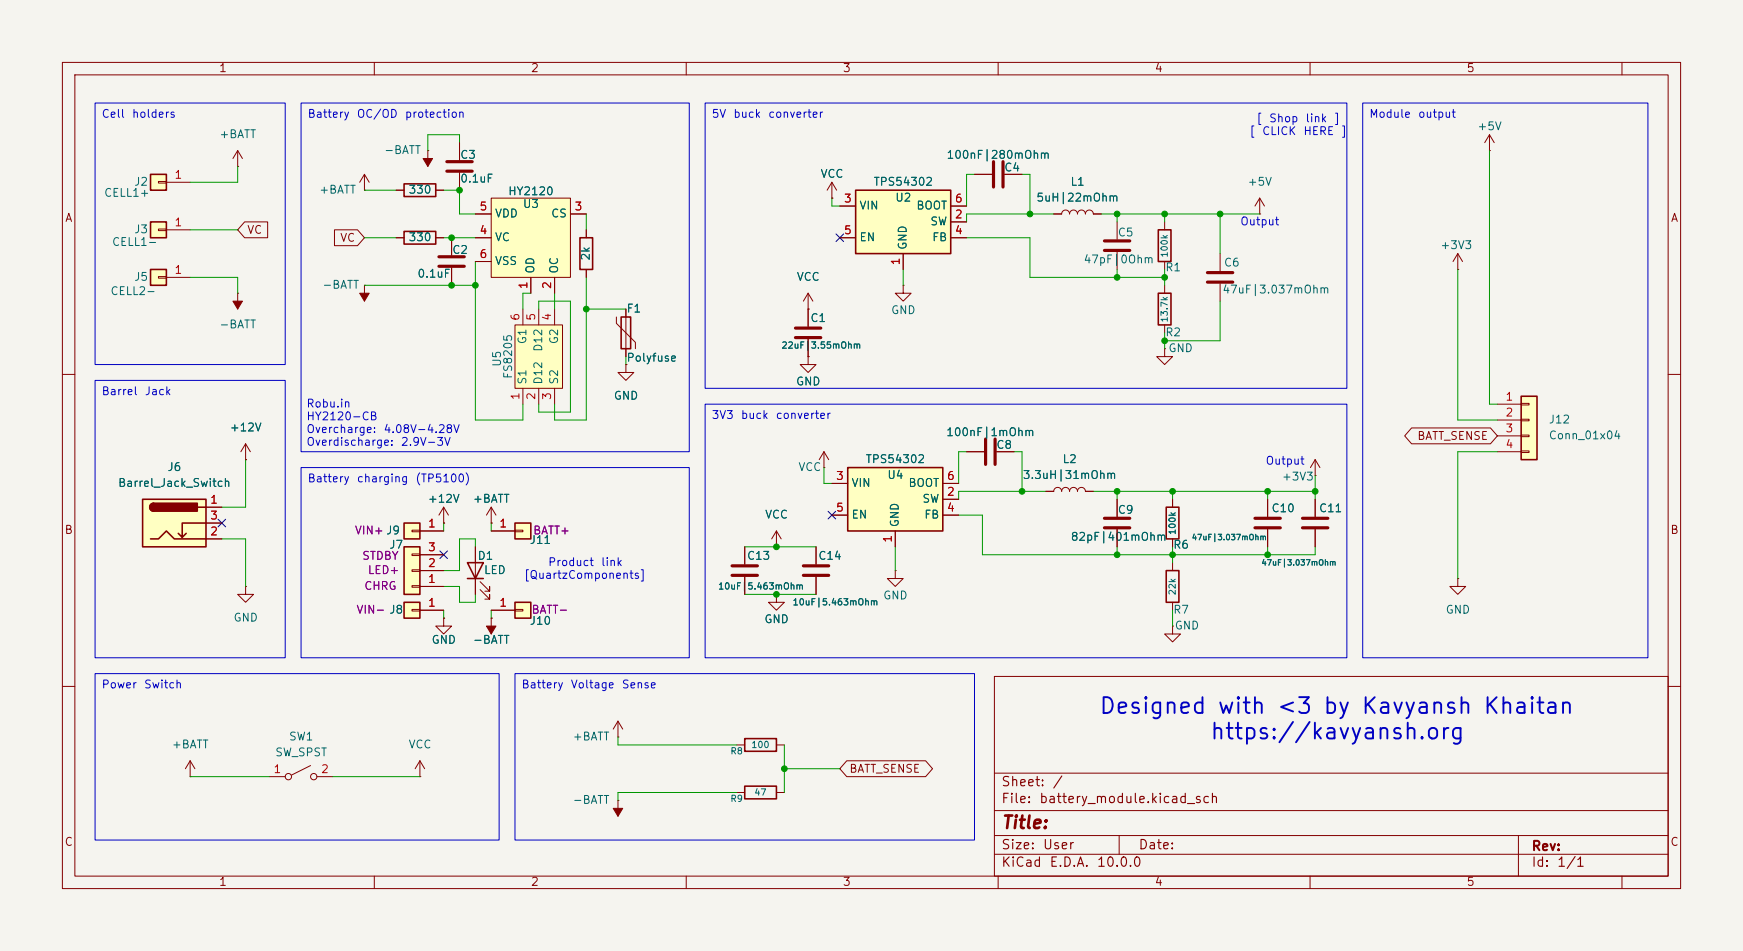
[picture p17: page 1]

Battery OC/OD protection
VSS 6 C3
VDD 5

6 U5 FS8205 -BATT +BATT R9 47 R8 100 +3V3 +5V -BATT +BATT 1

Designed with <3 by Kavyansh Khaitan

Size: User | Rev:

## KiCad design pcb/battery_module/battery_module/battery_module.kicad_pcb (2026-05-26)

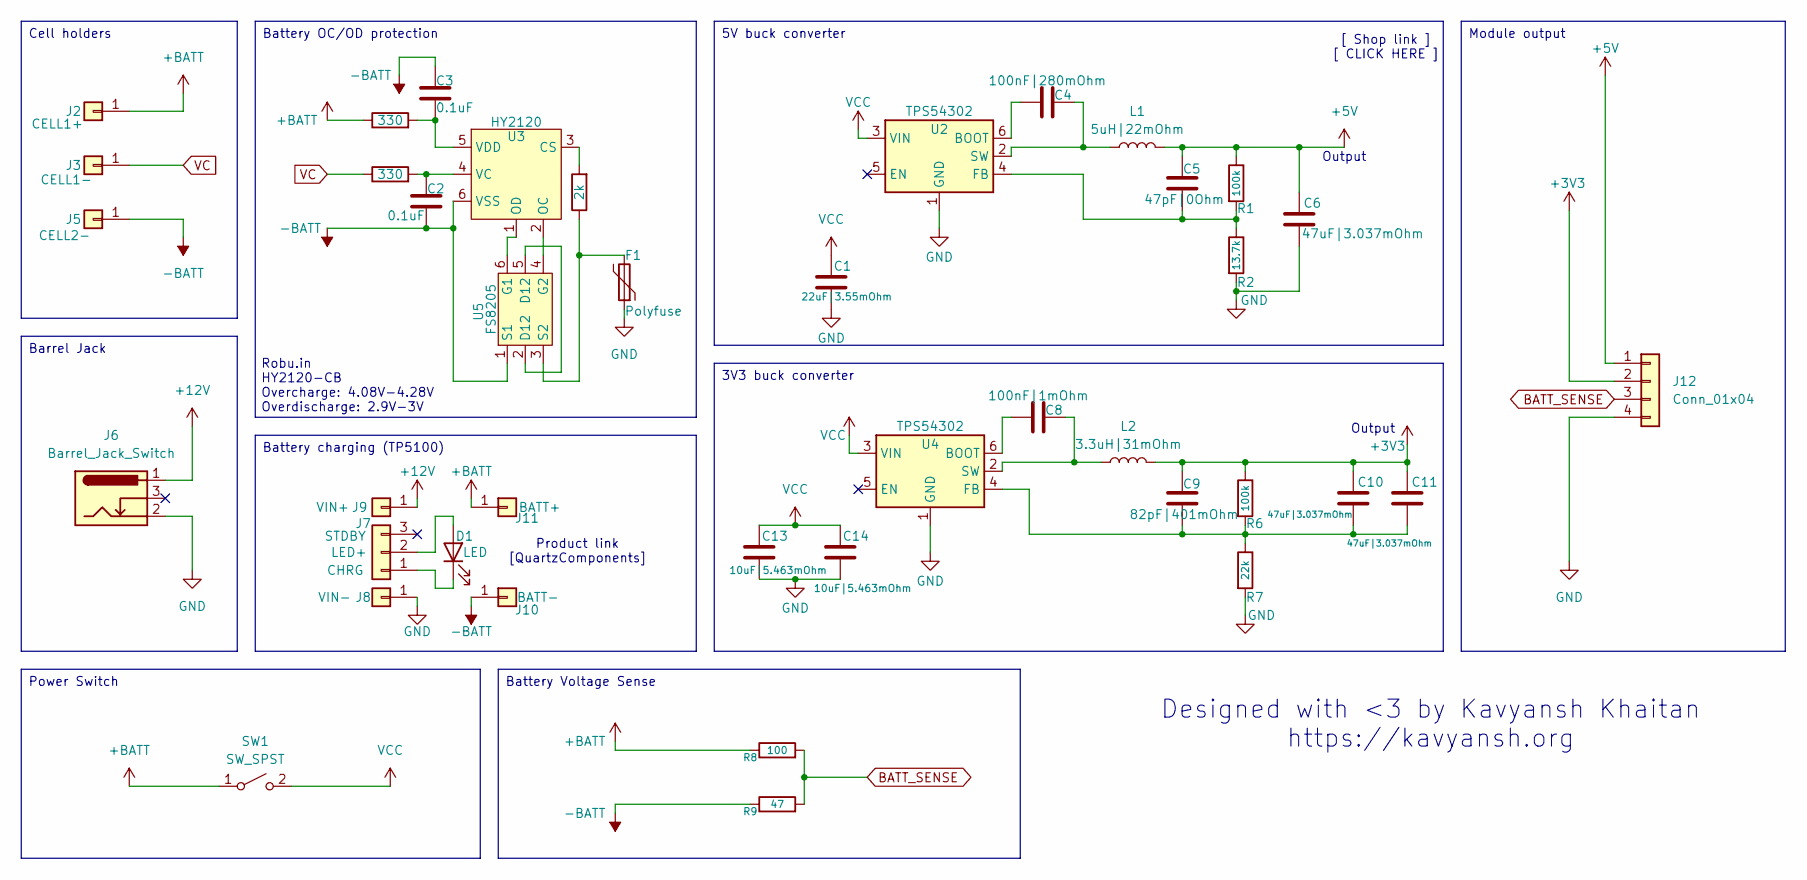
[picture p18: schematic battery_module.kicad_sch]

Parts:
C1: 22uF|3.55mOhm; C_0805_2012Metric_Pad1.18x1.45mm_HandSolder
C2, C3: 0.1uF; C_1206_3216Metric_Pad1.33x1.80mm_HandSolder
C4: 100nF|280mOhm; C_0805_2012Metric_Pad1.18x1.45mm_HandSolder
C5: 47pF|0Ohm; C_0805_2012Metric_Pad1.18x1.45mm_HandSolder
C6, C10, C11: 47uF|3.037mOhm; C_1210_3225Metric_Pad1.33x2.70mm_HandSolder
C8: 100nF|1mOhm; C_0805_2012Metric_Pad1.18x1.45mm_HandSolder
C9: 82pF|401mOhm; C_0805_2012Metric_Pad1.18x1.45mm_HandSolder
C13, C14: 10uF|5.463mOhm; C_0805_2012Metric_Pad1.18x1.45mm_HandSolder
D1: LED; LED_D2.0mm_W4.0mm_H2.8mm_FlatTop
F1: Polyfuse; Fuse_Littelfuse_395Series
J2: CELL1+; PinSocket_1x01_P2.54mm_Vertical
J3: CELL1-; PinSocket_1x01_P2.54mm_Vertical
J5: CELL2-; PinSocket_1x01_P2.54mm_Vertical
J6: Barrel_Jack_Switch; BarrelJack_Horizontal
J7: Conn_01x03; PinHeader_1x03_P2.00mm_Vertical
J8, J9, J10, J11: Conn_01x01; PinHeader_1x01_P2.54mm_Vertical
J12: Conn_01x04; PinSocket_1x04_P2.54mm_Vertical
L1: 5uH|22mOhm; L_APV_ANR8040
L2: 3.3uH|31mOhm; L_Bourns-SRN8040_8x8.15mm
R1, R6: 100k; R_1206_3216Metric_Pad1.30x1.75mm_HandSolder
R2: 13.7k; R_1206_3216Metric_Pad1.30x1.75mm_HandSolder
R4, R11: 330; R_1206_3216Metric_Pad1.30x1.75mm_HandSolder
R5: 2k; R_1206_3216Metric_Pad1.30x1.75mm_HandSolder
R7: 22k; R_1206_3216Metric_Pad1.30x1.75mm_HandSolder
R8: 100; R_Axial_DIN0207_L6.3mm_D2.5mm_P15.24mm_Horizontal
R9: 47; R_Axial_DIN0207_L6.3mm_D2.5mm_P15.24mm_Horizontal
SW1: SW_SPST; PinSocket_1x02_P2.54mm_Vertical
U2: TPS54302; SOT-23-6_Handsoldering
U3: HY2120; SOT-23-6_Handsoldering
U4: TPS54302; SOT-23-6
U5: FS8205; SOT-23-6_Handsoldering

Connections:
+3V3: C9.1, C10.1, C11.1, J12.2, L2.2, R6.1
+5V: C5.1, C6.1, J12.1, L1.2, R1.1
+12V: J6.1, J9.1 (Pin_1_1)
+BATT: J2.1 (Pin_1_1), J11.1 (Pin_1_1), R4.1, R8.1, SW1.1 (A)
-BATT: C2.2, C3.1, J5.1 (Pin_1_1), J10.1 (Pin_1_1), R9.1, U3.6 (VSS), U5.1 (S1)
BATT_SENSE: J12.3, R8.2, R9.2
GND: C1.2, C6.2, C13.2, C14.2, F1.1, J6.2, J8.1 (Pin_1_1), J12.4, R2.2, R7.2, U2.1 (GND), U4.1 (GND)
unnamed: D1.2 (A), J7.2
unnamed: D1.1 (K), J7.1
unnamed: C4.1, U2.6 (BOOT)
unnamed: C5.2, R1.2, R2.1, U2.4 (FB)
unnamed: C4.2, L1.1, U2.2 (SW)
unnamed: R5.2, U3.3 (CS)
unnamed: U3.2 (OC), U5.4 (G2)
unnamed: U3.1 (OD), U5.6 (G1)
unnamed: C2.1, R11.2, U3.4 (VC)
unnamed: C3.2, R4.2, U3.5 (VDD)
unnamed: C8.1, U4.6 (BOOT)
unnamed: C9.2, C10.2, C11.2, R6.2, R7.1, U4.4 (FB)
unnamed: C8.2, L2.1, U4.2 (SW)
unnamed: U5.2 (D12), U5.5 (D12)
unnamed: F1.2, R5.1, U5.3 (S2)
VC: J3.1 (Pin_1_1), R11.1
VCC: C1.1, C13.1, C14.1, SW1.2 (B), U2.3 (VIN), U4.3 (VIN)

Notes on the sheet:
Output
Product link [QuartzComponents]
[ Shop link ] [ CLICK HERE ]
Designed with <3 by Kavyansh Khaitan https://kavyansh.org
Robu.in HY2120-CB Overcharge: 4.08V-4.28V Overdischarge: 2.9V-3V
Cell holders
Module output
Power Switch
Battery charging (TP5100)
Battery Voltage Sense
3V3 buck converter
Battery OC/OD protection
5V buck converter
Barrel Jack

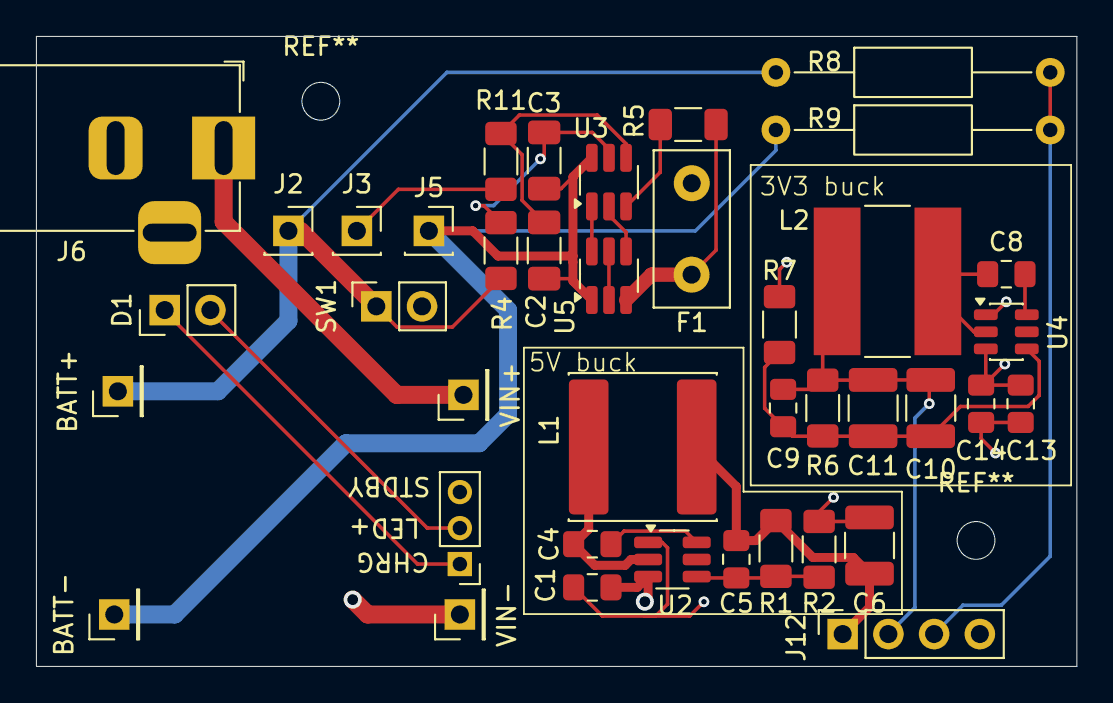
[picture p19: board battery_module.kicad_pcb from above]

Board: 4 copper layers, 57.8 x 35.0 mm, 40 parts (0 on the bottom side), 24 nets.

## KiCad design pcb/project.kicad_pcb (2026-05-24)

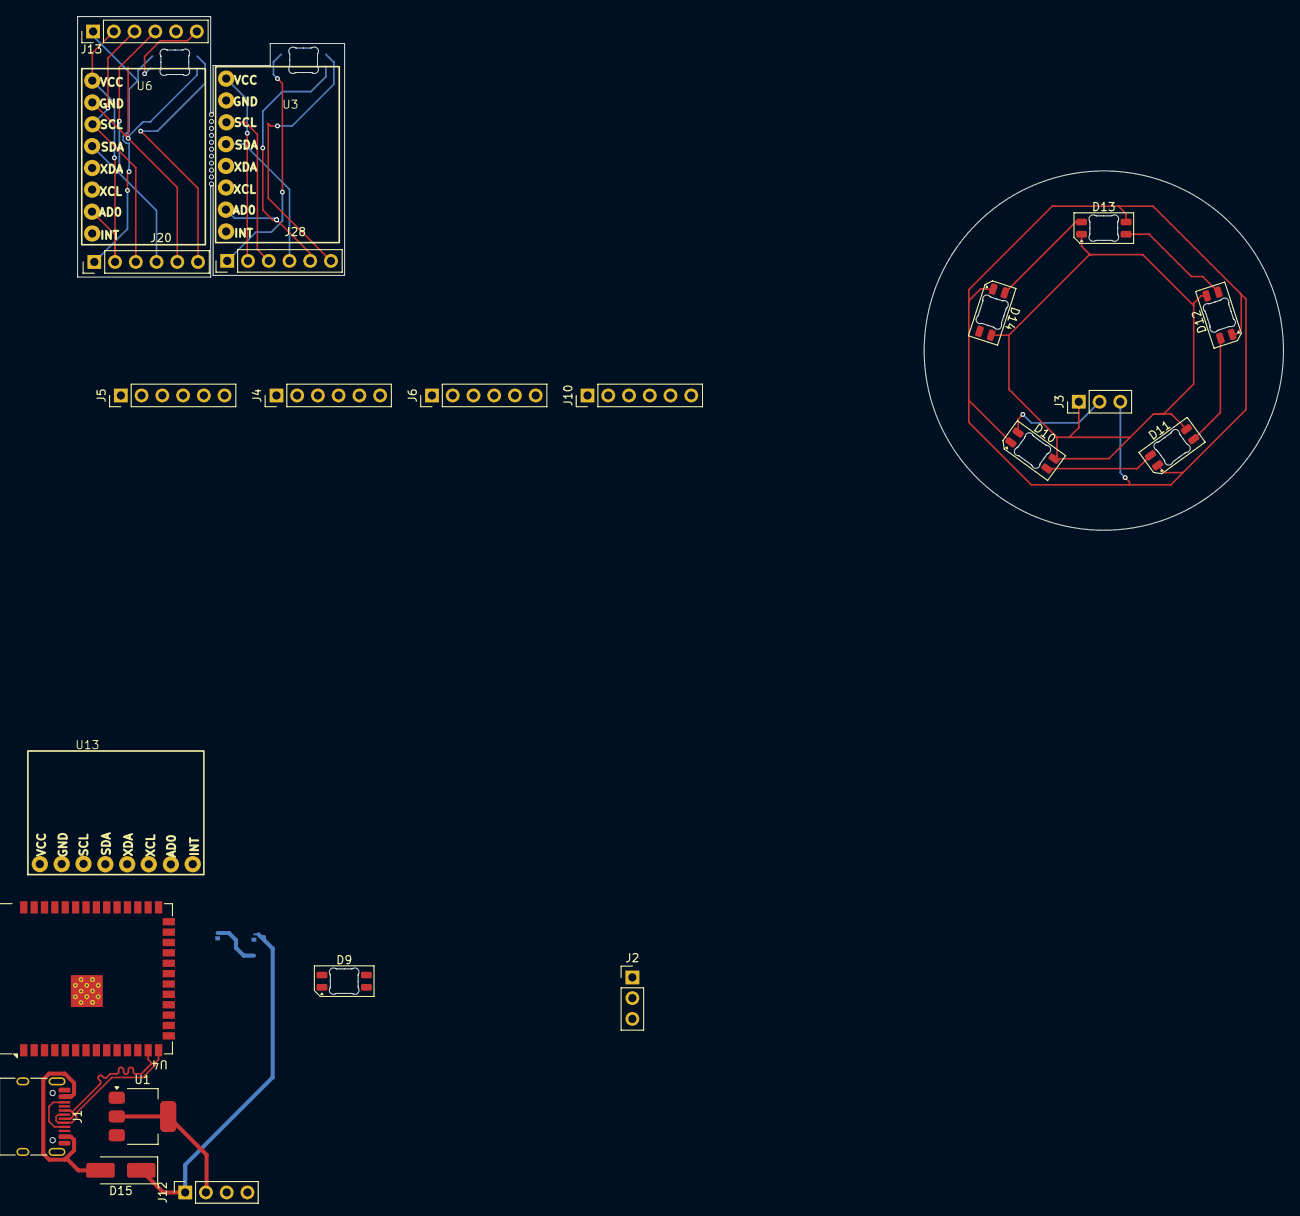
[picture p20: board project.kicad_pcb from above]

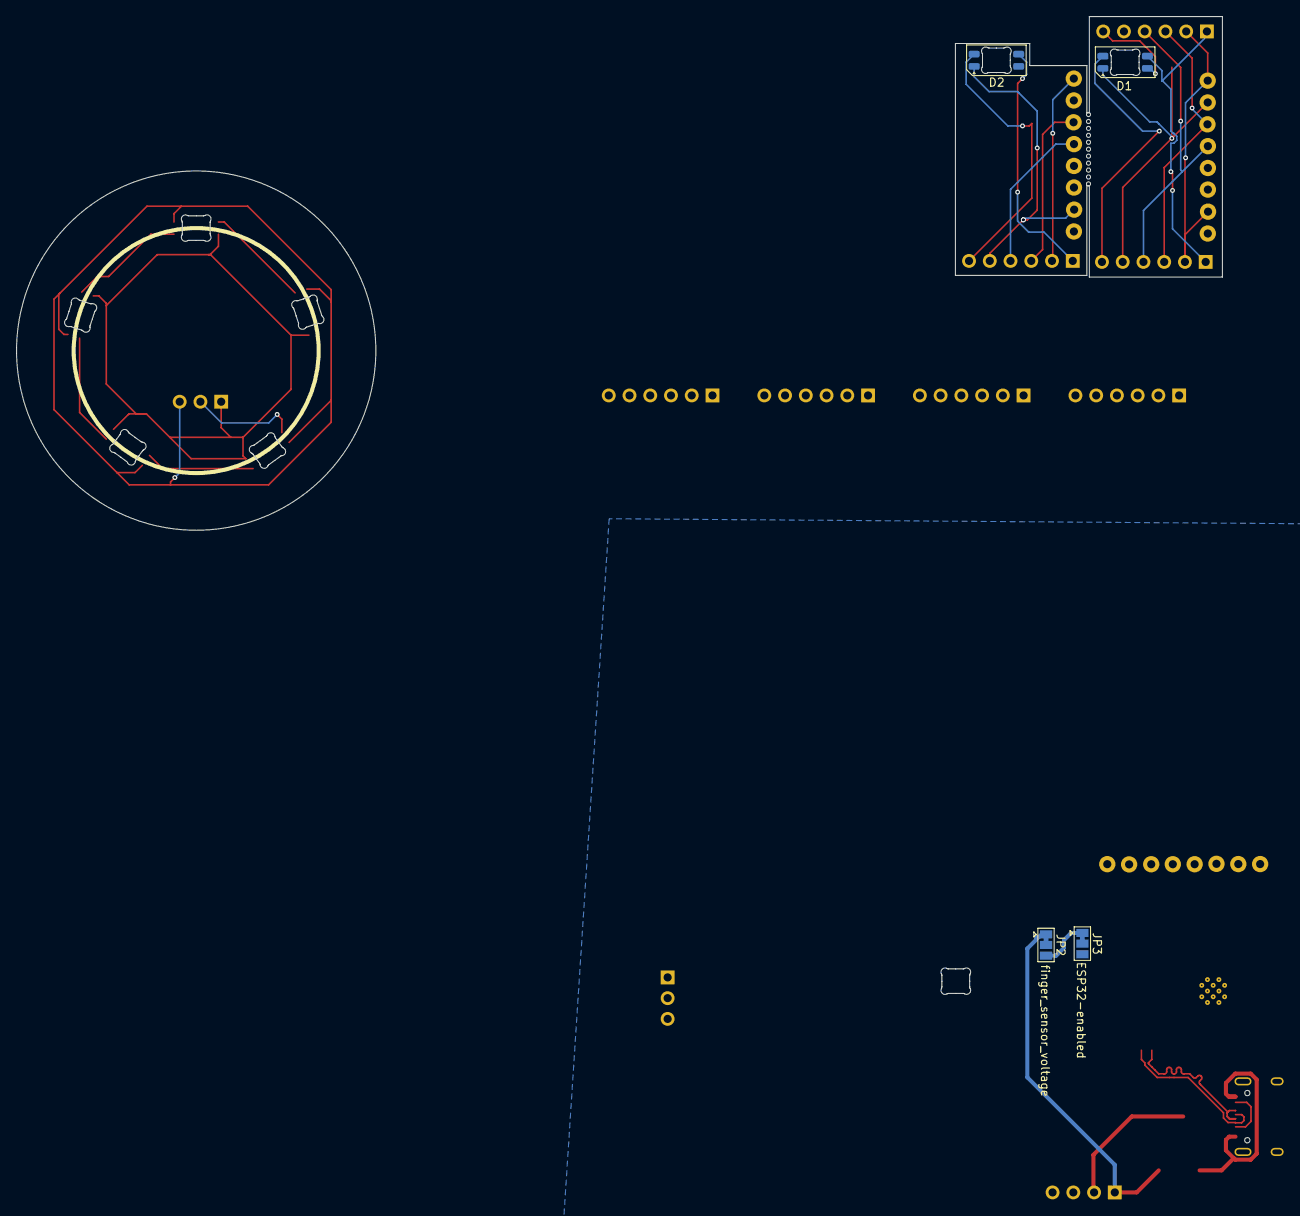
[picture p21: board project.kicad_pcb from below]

Board: 2 copper layers, 147.7 x 119.7 mm, 27 parts (4 on the bottom side), 45 nets.

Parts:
D1, D2, D9, D10, D11, D12, D13, D14: SK6812MINI-E; LED_SK6812MINI-E_3.2x2.8mm_P1.5mm_ReverseMount
D15: D; D_SMA_Handsoldering
J1: USB_C_Receptacle_USB2.0_14P; USB_C_Receptacle_HRO_TYPE-C-31-M-12
J2, J3: Conn_01x03; PinHeader_1x03_P2.54mm_Vertical
J4, J5, J6, J10, J13, J20, J28: Conn_01x06; PinHeader_1x06_P2.54mm_Vertical
J12: Conn_01x04; PinSocket_1x04_P2.54mm_Vertical
JP2: finger_sensor_voltage; SolderJumper-3_P1.3mm_Bridged12_Pad1.0x1.5mm
JP3: ESP32-enabled; SolderJumper-3_P1.3mm_Bridged12_Pad1.0x1.5mm
U1: LM1117MP-3.3; SOT-223-3_TabPin2
U3, U6, U13: GY-521; MPU-6050
U4: ESP32-S3-WROOM-1

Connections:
+3V3: J12.2, JP2.3 (B), JP3.1 (A), U1.2 (VO), U4.2 (3V3)
+5V: D9.3 (VDD), D15.1 (K), J2.1, J4.1, J5.1, J6.1, J10.1, J12.1, JP2.1 (A)
BATT_SENSE: J12.3, U4.8 (IO15)
GND: D9.1 (VSS), J1.A1 (GND), J1.A12 (GND), J1.B1 (GND), J1.B12 (GND), J1.SH (SHIELD), J2.3, J4.5, J5.5, J6.5, J10.5, J12.4, JP3.3 (B), U1.1 (GND), U4.1 (GND), U4.40 (GND), U4.41 (GND), U13.2 (GND)
LED0: D9.2 (DIN), U4.27 (IO0)
LED1: J4.6, U4.39 (IO1)
LED2: J5.6, U4.38 (IO2)
LED3: J6.6, U4.15 (IO3)
LED4: J10.6, U4.4 (IO4)
unnamed: D1.2 (DIN), J20.6
unnamed: D1.4 (DOUT), J13.6
unnamed: D1.3 (VDD), J13.1, J20.1
unnamed: D1.1 (VSS), J13.5, J20.5, U6.2 (GND)
unnamed: D2.2 (DIN), J28.6
unnamed: D2.3 (VDD), J28.1
unnamed: D2.1 (VSS), J28.5, U3.2 (GND), U3.7 (AD0)
unnamed: D9.4 (DOUT), J2.2
unnamed: D10.2 (DIN), J3.2
unnamed: D10.4 (DOUT), D11.2 (DIN)
unnamed: D10.3 (VDD), D11.3 (VDD), D12.3 (VDD), D13.3 (VDD), D14.3 (VDD), J3.1
unnamed: D10.1 (VSS), D11.1 (VSS), D12.1 (VSS), D13.1 (VSS), D14.1 (VSS), J3.3
unnamed: D11.4 (DOUT), D12.2 (DIN)
unnamed: D12.4 (DOUT), D13.2 (DIN)
unnamed: D13.4 (DOUT), D14.2 (DIN)
unnamed: D15.2 (A), J1.A4 (VBUS), J1.A9 (VBUS), J1.B4 (VBUS), J1.B9 (VBUS), U1.3 (VI)
unnamed: J4.2, J5.2, J6.2, J10.2, JP2.2 (C), U13.1 (VCC), U13.7 (AD0)
unnamed: J13.2, J20.2, U6.1 (VCC), U6.7 (AD0)
unnamed: J13.3, J20.3, U6.3 (SCL)
unnamed: J13.4, J20.4, U6.4 (SDA)
unnamed: J28.2, U3.1 (VCC)
unnamed: J28.3, U3.3 (SCL)
unnamed: J28.4, U3.4 (SDA)
unnamed: JP3.2 (C), U4.3 (EN)
SC0: J4.3, U4.5 (IO5)
SC1: J5.3, U4.7 (IO7)
SC2: J6.3, U4.17 (IO9)
SC3: J10.3, U4.19 (IO11)
SC4: U4.21 (IO13), U13.3 (SCL)
SD0: J4.4, U4.6 (IO6)
SD1: J5.4, U4.12 (IO8)
SD2: J6.4, U4.18 (IO10)
SD3: J10.4, U4.20 (IO12)
SD4: U4.22 (IO14), U13.4 (SDA)
USB_D+: J1.A6 (D+), J1.B6 (D+), U4.14 (USB_D+)
USB_D-: J1.A7 (D-), J1.B7 (D-), U4.13 (USB_D-)

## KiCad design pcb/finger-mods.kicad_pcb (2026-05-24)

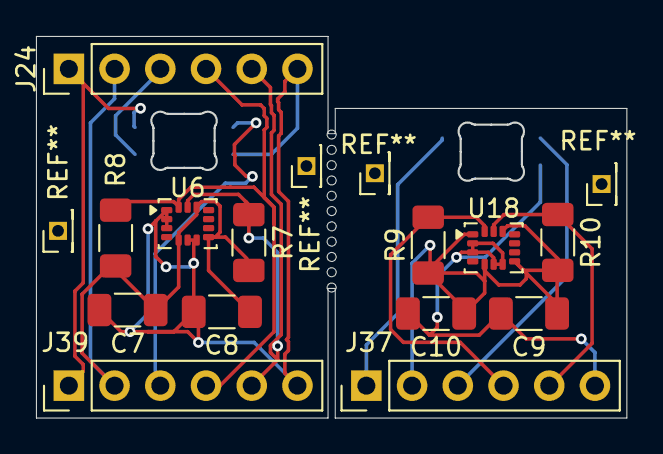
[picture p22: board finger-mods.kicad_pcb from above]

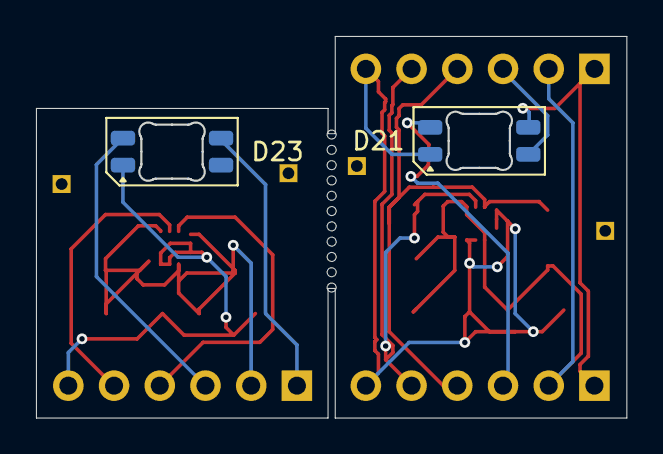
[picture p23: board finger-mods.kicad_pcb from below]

Board: 2 copper layers, 32.8 x 21.2 mm, 15 parts (2 on the bottom side), 10 nets.

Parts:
C7, C8, C9, C10: 100nF; C_1206_3216Metric_Pad1.33x1.80mm_HandSolder
D21, D23: SK6812MINI-E; LED_SK6812MINI-E_3.2x2.8mm_P1.5mm_ReverseMount
J24, J37, J39: Conn_01x06; PinHeader_1x06_P2.54mm_Vertical
R7, R8, R9, R10: 10k; R_1206_3216Metric_Pad1.30x1.75mm_HandSolder
U6, U18: LSM6DS3; LGA-14_3x2.5mm_P0.5mm_LayoutBorder3x4y

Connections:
+3V3: C7.1, C8.1, C9.1, C10.1, J24.2, J37.2, J39.2, R7.1, R8.1, R9.1, R10.1, U6.5 (VDDIO), U6.8 (VDD), U6.12 (CS), U18.1 (SDO/SA0), U18.5 (VDDIO), U18.8 (VDD), U18.12 (CS)
+5V: D21.3 (VDD), D23.3 (VDD), J24.1, J37.1, J39.1
/DIN: D21.2 (DIN), J39.3
/Finger Module P2/DIN: D23.2 (DIN), J37.3
/Finger Module P2/SCL: J37.5, R10.2, U18.13 (SCL)
/Finger Module P2/SDA: J37.4, R9.2, U18.14 (SDA)
/SCL: J24.5, J39.5, R7.2, U6.13 (SCL)
/SDA: J24.4, J39.4, R8.2, U6.14 (SDA)
GND: C7.2, C8.2, C9.2, C10.2, D21.1 (VSS), D23.1 (VSS), J24.6, J37.6, J39.6, U6.1 (SDO/SA0), U6.2 (SDX), U6.3 (SCX), U6.6 (GND), U6.7 (GND), U18.2 (SDX), U18.3 (SCX), U18.6 (GND), U18.7 (GND)
unnamed: D21.4 (DOUT), J24.3

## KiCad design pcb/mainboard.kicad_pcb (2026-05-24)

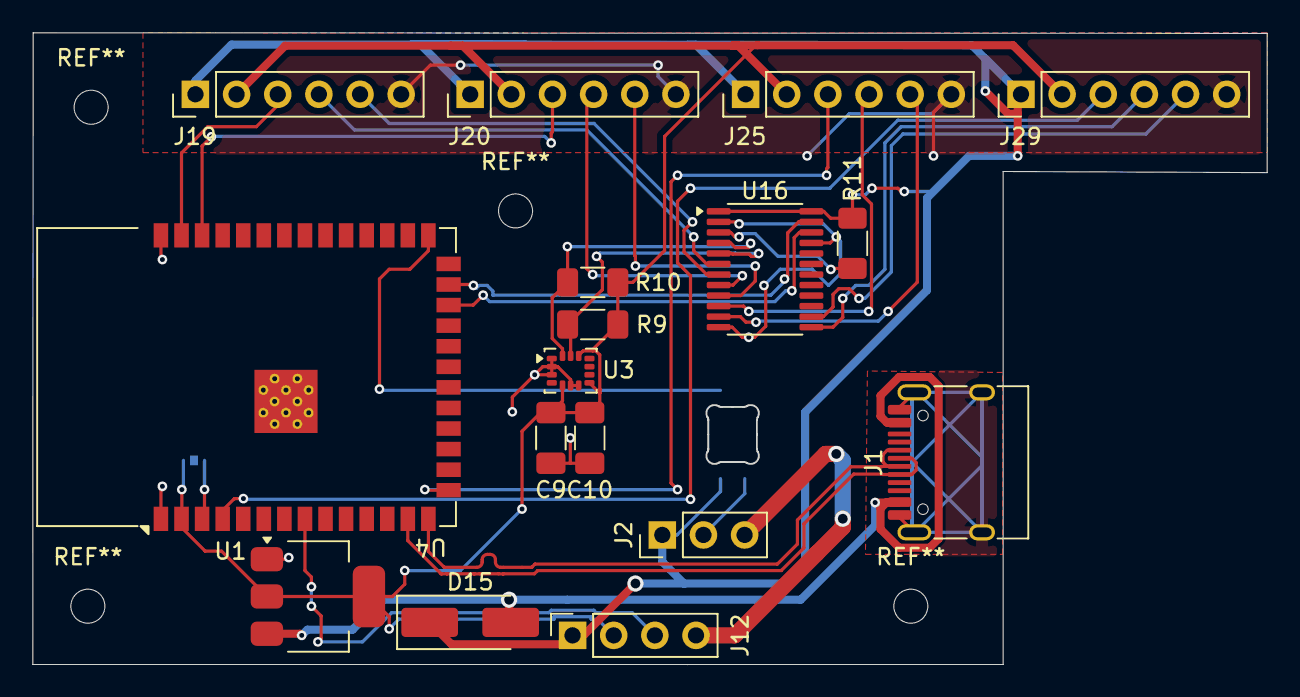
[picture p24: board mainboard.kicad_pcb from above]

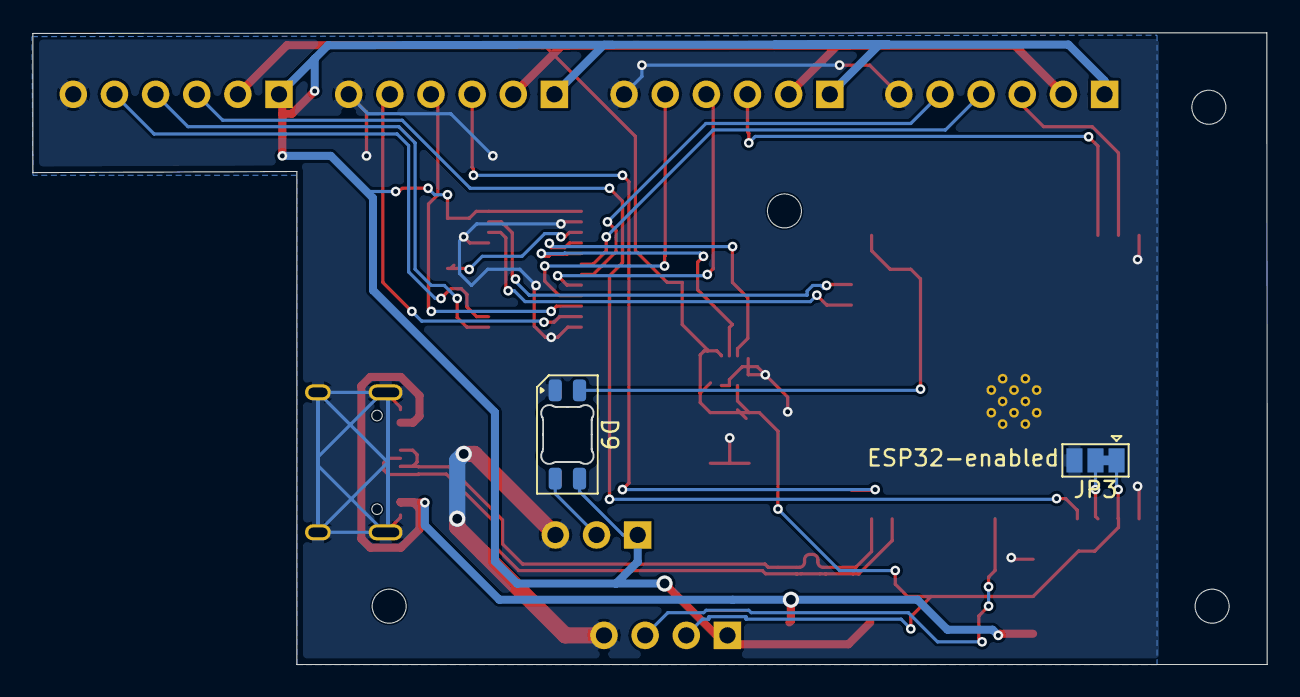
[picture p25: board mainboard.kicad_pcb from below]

Board: 2 copper layers, 76.2 x 39.0 mm, 19 parts (2 on the bottom side), 27 nets.

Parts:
C9, C10: 100nF; C_1206_3216Metric_Pad1.33x1.80mm_HandSolder
D9: SK6812MINI-E; LED_SK6812MINI-E_3.2x2.8mm_P1.5mm_ReverseMount
D15: D; D_SMA_Handsoldering
J1: USB_C_Receptacle_USB2.0_14P; USB_C_Receptacle_HRO_TYPE-C-31-M-12
J2: Conn_01x03; PinHeader_1x03_P2.54mm_Vertical
J12: Conn_01x04; PinSocket_1x04_P2.54mm_Vertical
J19, J20, J25, J29: Conn_01x06; PinHeader_1x06_P2.54mm_Vertical
JP3: ESP32-enabled; SolderJumper-3_P1.3mm_Bridged12_Pad1.0x1.5mm
R9, R10, R11: 10k; R_1206_3216Metric_Pad1.30x1.75mm_HandSolder
U1: LM1117MP-3.3; SOT-223-3_TabPin2
U3: LSM6DS3; LGA-14_3x2.5mm_P0.5mm_LayoutBorder3x4y
U4: ESP32-S3-WROOM-1
U16: TCA9548APWR; TSSOP-24_4.4x7.8mm_P0.65mm

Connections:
+3V3: C9.1, C10.1, J12.2, J19.2, J20.2, J25.2, J29.2, JP3.1 (A), R9.1, R10.1, U1.2 (VO), U3.5 (VDDIO), U3.8 (VDD), U3.12 (CS), U4.2 (3V3)
+5V: D9.3 (VDD), D15.1 (K), J2.1, J12.1, J19.1, J20.1, J25.1, J29.1, R11.1, U16.1 (A0), U16.24 (VCC)
BATT_SENSE: J12.3, U4.8 (IO15)
GND: C9.2, C10.2, D9.1 (VSS), J1.A1 (GND), J1.A12 (GND), J1.B1 (GND), J1.B12 (GND), J1.SH (SHIELD), J2.3, J12.4, J19.6, J20.6, J25.6, J29.6, JP3.3 (B), U1.1 (GND), U3.1 (SDO/SA0), U3.2 (SDX), U3.3 (SCX), U3.6 (GND), U3.7 (GND), U4.1 (GND), U4.40 (GND), U4.41 (GND), U16.2 (A1), U16.12 (GND), U16.21 (A2)
LED0: D9.2 (DIN), U4.27 (IO0)
LED1: J19.3, U4.39 (IO1)
LED2: J20.3, U4.38 (IO2)
LED3: J25.3, U4.15 (IO3)
LED4: J29.3, U4.4 (IO4)
unnamed: D9.4 (DOUT), J2.2
unnamed: D15.2 (A), J1.A4 (VBUS), J1.A9 (VBUS), J1.B4 (VBUS), J1.B9 (VBUS), U1.3 (VI)
unnamed: JP3.2 (C), U4.3 (EN)
unnamed: U4.24 (IO47), U16.22 (SCL)
unnamed: U4.25 (IO48), U16.23 (SDA)
unnamed: R11.2, U16.3 (~RESET)
SC0: R9.2, U3.13 (SCL), U16.5 (SC0)
SC1: J19.5, U16.7 (SC1)
SC2: J20.5, U16.9 (SC2)
SC3: J25.5, U16.11 (SC3)
SC4: J29.5, U16.14 (SC4)
SD0: R10.2, U3.14 (SDA), U16.4 (SD0)
SD1: J19.4, U16.6 (SD1)
SD2: J20.4, U16.8 (SD2)
SD3: J25.4, U16.10 (SD3)
SD4: J29.4, U16.13 (SD4)
USB_D+: J1.A6 (D+), J1.B6 (D+), U4.14 (USB_D+)
USB_D-: J1.A7 (D-), J1.B7 (D-), U4.13 (USB_D-)

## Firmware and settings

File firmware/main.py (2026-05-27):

import machine
from machine import Pin
from neopixel import NeoPixel
from time import sleep

batt_sense = Pin(15, Pin.IN)
_leds_mainboard = Pin(0, Pin.OUT)
leds_mainboard = NeoPixel(_leds_mainboard, 6)

_leds_f1 = Pin(1, Pin.OUT)
leds_f1 = NeoPixel(_leds_f1, 2)
_leds_f2 = Pin(2, Pin.OUT)
leds_f2 = NeoPixel(_leds_f2, 2)
_leds_f3 = Pin(3, Pin.OUT)
leds_f3 = NeoPixel(_leds_f3, 2)
_leds_f4 = Pin(4, Pin.OUT)
leds_f4 = NeoPixel(_leds_f4, 2)

i2c_mplx_cl = Pin(47, Pin.OUT)
i2c_mplx_da = Pin(48)

i = 0
while True:
    for _ in range(6):
        leds_mainboard[_] = [i,i,i]
    leds_mainboard.write()
    for _ in range(2):
        leds_f1[_] = [i,i,i]
        leds_f2[_] = [i,i,i]
        leds_f3[_] = [i,i,i]
        leds_f4[_] = [i,i,i]

    leds_f1.write()
    leds_f2.write()
    leds_f3.write()
    leds_f4.write()
    i += 4
    i %= 256
    
    sleep(0.01)

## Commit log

2026-05-26 Organised files a bit
    [battery_module.kicad_pcb, project.csv, project.kicad_sch]
2026-05-26 Add production
    [Mainboard case - Part 1.stl, Mainboard case - Part 2.stl, Mainboard case - Part 3.stl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]
2026-05-26 Update production
    [backleds.kicad_pcb, bom.csv, designators.csv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]
2026-05-26 Updated BOM with links
2026-05-27 Add BOM.csv
    [BOM.csv]
2026-05-27 Add GitHub link for BOM CSV file
    Added link to open CSV file in GitHub for BOM.
2026-05-27 Remove excess BOMs
    [bom.csv]
2026-06-08 Add assembly section to README
    Added assembly instructions to the README.
2026-06-08 Enhance assembly section with clearer steps and images
    Updated assembly instructions for clarity and added images.
2026-06-11 Add new image to final assembly section in README
